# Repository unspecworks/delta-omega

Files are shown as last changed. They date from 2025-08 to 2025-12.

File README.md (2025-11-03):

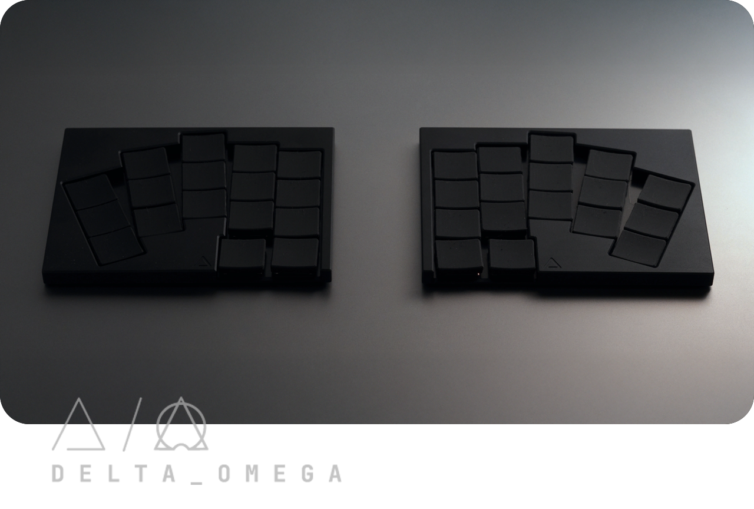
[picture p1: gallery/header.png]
DELTA OMEGA


# DELTA OMEGA

A portable ultra-low-profile (ULP) wireless 3×5+2 split keyboard.

## Overview

- Switch support: Cherry MX ULP or Kailh PG1316s
- 34 keys, splayed and staggered with choc spacing
- Wireless
- CNC aluminum case

## Parameters

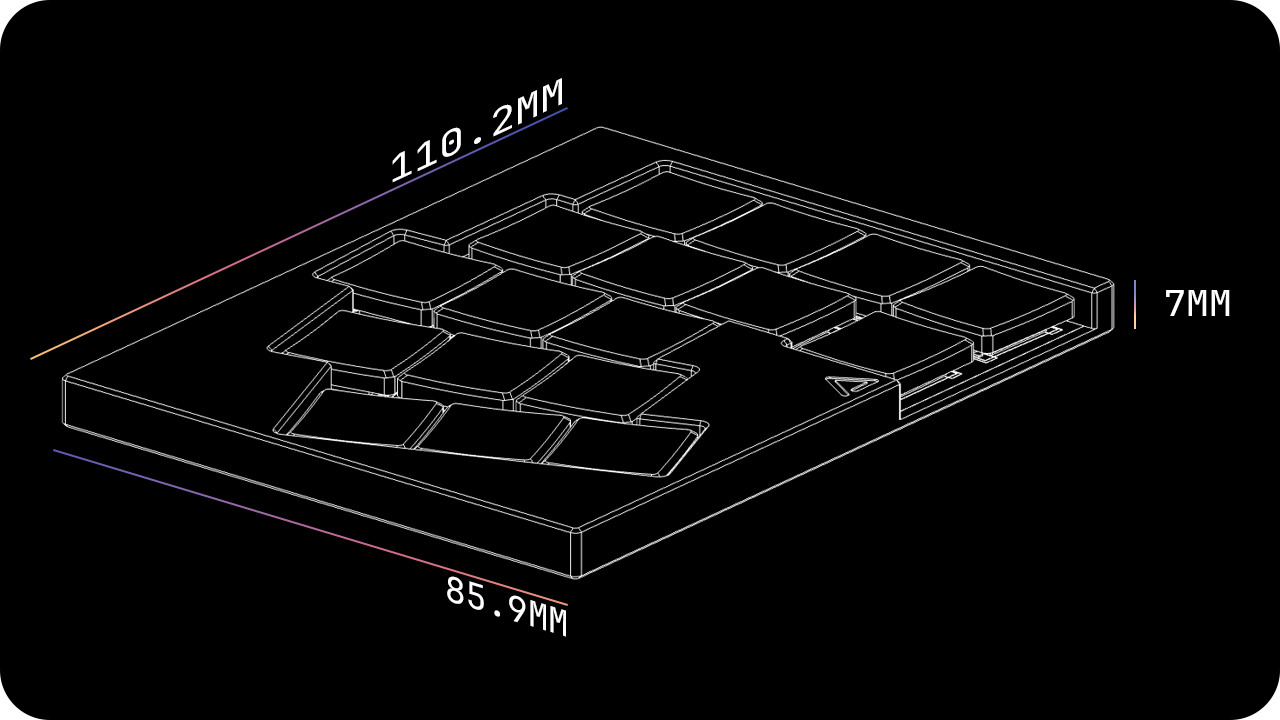
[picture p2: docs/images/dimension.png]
Dimension


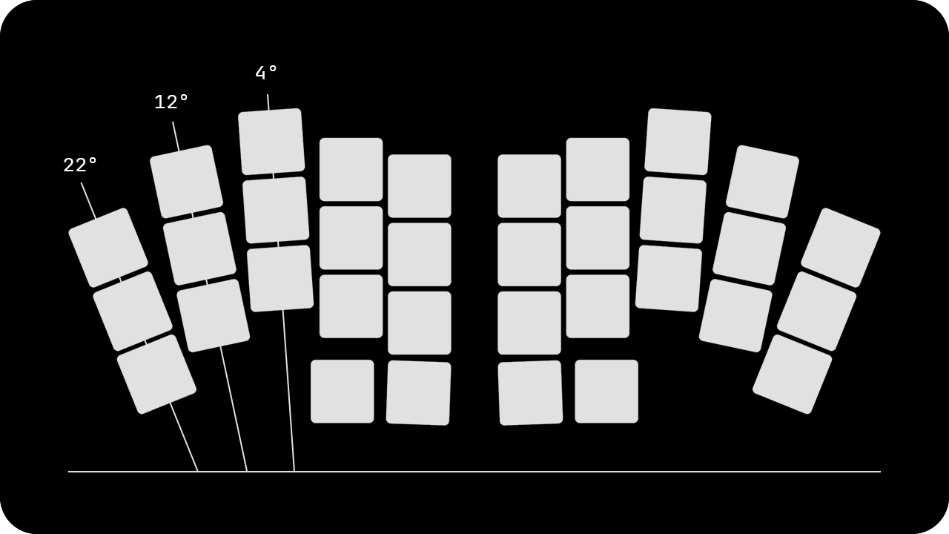
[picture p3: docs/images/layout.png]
Layout


## Documentation

> [!NOTE]
> This is **not** a typical low-profile (LP) or MX build. While it may look familiar, there are enough differences here that skipping the documentation could cause issues. Please take the time to read all notes and guides before starting.

- [Getting Started](./docs/GETTING_STARTED.md)
- [Bill of Materials](./docs/BOM.md)
- [Build Guides](./docs/BUILD_GUIDES.md)
- [Video](https://youtu.be/UktrqN3MlLI)
- [PCB](./pcb/README.md)
- [Case](./case/README.md)
- [ZMK Keyboard Module](https://github.com/unspecworks/zmk-keyboard-delta-omega)
- [Pre-conf ZMK Config](https://github.com/unspecworks/zmk-delta-omega)
- Keycaps
  - [Delta ULP Keycap](https://github.com/unspecworks/delta-ulp-keycap)

## Photos

- [Gallery](./gallery/README.md)
- [Prototype Gallery](./images/README.md)
  - Diff: Port position, Thumb-cluster layout and only hot-plate way.

## Acknowledgments and Inspirations

- [GEIGEIGEIST/TOTEM](https://github.com/GEIGEIGEIST/TOTEM)
- [mikeholscher/zmk-config-mikecinq](https://github.com/mikeholscher/zmk-config-mikecinq)
- [pashutk/Cherry_MX_ULP](https://github.com/pashutk/Cherry_MX_ULP)
- [zmk-rgbled-widget](https://github.com/caksoylar/zmk-rgbled-widget)
- [infused-kim/kb_ergogen_fp](https://github.com/infused-kim/kb_ergogen_fp)
- [ceoloide/ergogen-footprints](https://github.com/ceoloide/ergogen-footprints)
- [kiswitch/kiswitch](https://github.com/kiswitch/kiswitch)

## Limitations and Disclaimer

This is a hobby-driven project. Some aspects may be incomplete, imperfect, or problematic. Use this project **at your own risk**, and note that no warranties or guarantees are provided.

## License

DELTA OMEGA is licensed under [CERN-OHL-W-2.0](./LICENSE.md).

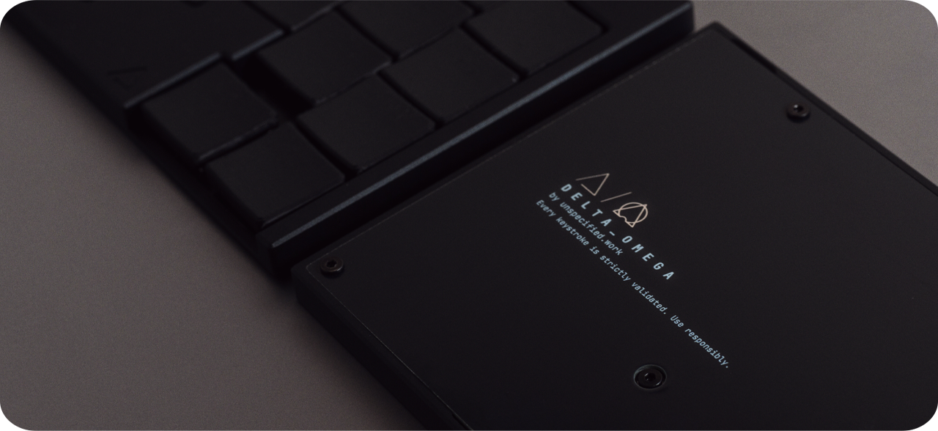
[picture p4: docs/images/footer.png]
footer


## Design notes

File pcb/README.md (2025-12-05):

# PCB

> [!TIP]
> If this is your first visit, please read the [Getting Started guide](./../docs/GETTING_STARTED.md) first.

---

## PCB List

| File | Description | Note |
|---|---|---|
| `delta-omega-rev4-handsolder-both` | Main Left & Right PCB with mouse-bite connection | MB Not tested. |
| `delta-omega-rev4-handsolder-left` | Main Left PCB | |
| `delta-omega-rev4-handsolder-right` | Main Right PCB | |
| `delta_omega_bottom_cover` | Bottom cover PCB plate | Reversible |
| ... |  |  |
| `delta-omega-rev4-smd-both` | SMD Version | :warning: NOT TESTED |

---

## How to Order

This guide is written based on **[JLCPCB](https://jlcpcb.com)**. While other PCB manufacturers may differ slightly, most ordering steps are very similar.

To place an order, you will need the **Gerber archive**. Simply upload the ZIP file found in [./gerbers/](./gerbers/) to the JLCPCB order page.

> [!NOTE]
> In JLCPCB’s Gerber Viewer, the edge cuts for hand-soldering switch may not appear. This is a known JLCPCB viewer issue and does **not** affect the actual manufacturing.

---

### Recommended Options

| Specification | Recommended | Notes |
|---|---|---|
| Base Material | FR-4 | Standard PCB substrate material |
| Layers | 2 | Two-layer board |
| PCB Quantity | As many as needed | |
| Product Type | Industrial / Consumer Electronics | |
| Different Designs | 1 | If uploading a combined left & right PCB Gerber, select **2**.[^1] |
| PCB Thickness | 0.8 mm or 1.6 mm | See [Getting Started](./../docs/GETTING_STARTED.md) for details |
| PCB Color | Your preference | |
| Surface Finish | Your preference | |
| Mark on PCB | Remove Mark | Recommended for a cleaner finish |

[^1]: If not selected, JLCPCB will automatically review your order and guide you to the correct option.

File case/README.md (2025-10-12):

# Case

### Default Case STEP Files
- `delta_omega_rev2_left.step`
- `delta_omega_rev2_right.step`

### Thread Annotation Drawings
These images **must be uploaded when placing an order** to ensure correct threading specifications:
- `delta_omega_rev2_left_thread.png`
- `delta_omega_rev2_right_thread.png`

---

## How to Order

This instructions are **based on JLC CNC**. While other CNC manufacturing services may follow slightly different requirements, in practice most specifications are very similar.

- **Material**: Aluminum 6061 (or something)
- **Surface Finish**: Bead blasting + anodizing recommended
- **Tightest Tolerance**: ISO 2768 (medium) is sufficient
- **Surface Roughness**: Ra3.2 is sufficient
- **Threads**: Yes. be sure to upload the thread annotation images (`left` / `right`) with your order

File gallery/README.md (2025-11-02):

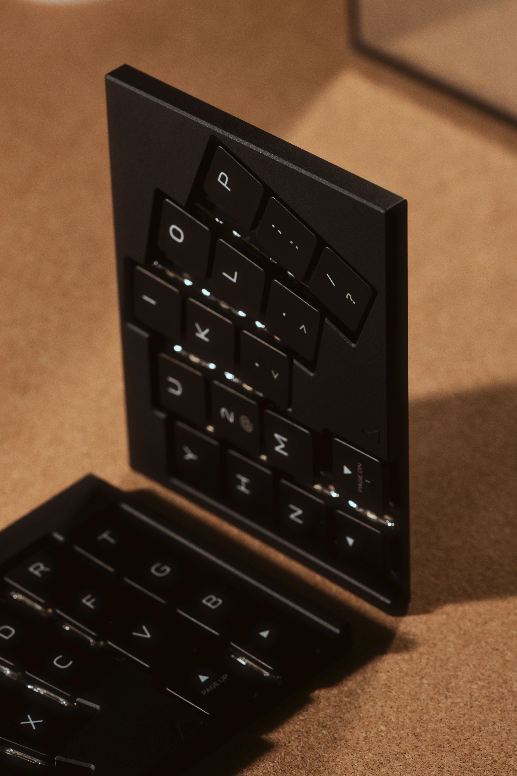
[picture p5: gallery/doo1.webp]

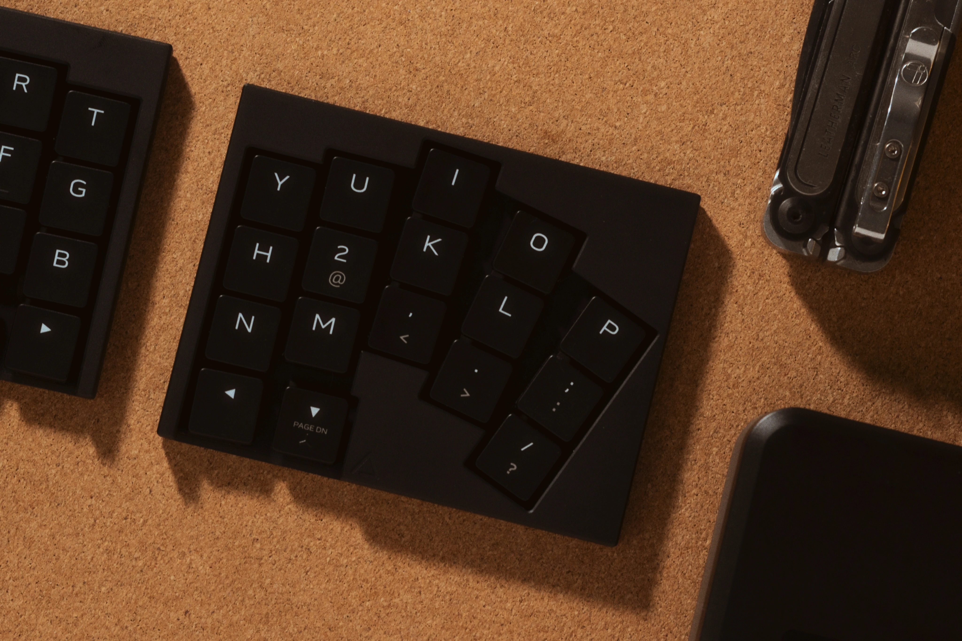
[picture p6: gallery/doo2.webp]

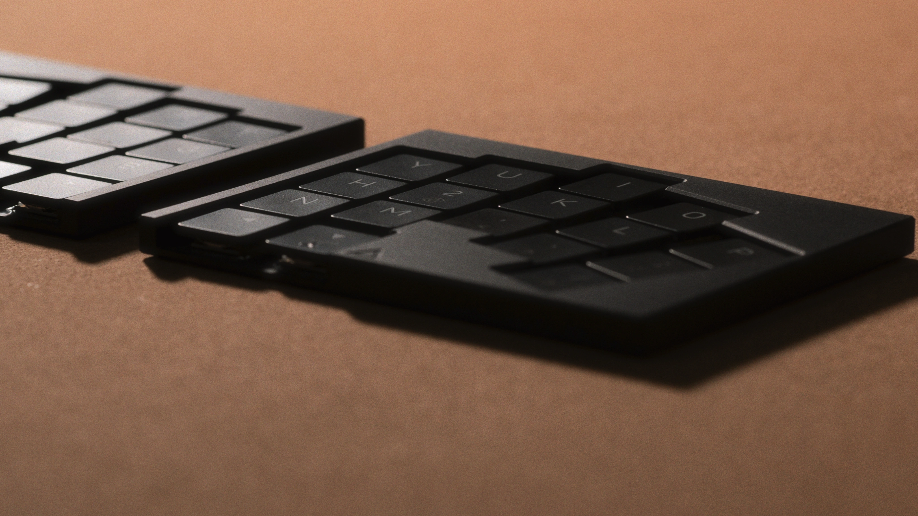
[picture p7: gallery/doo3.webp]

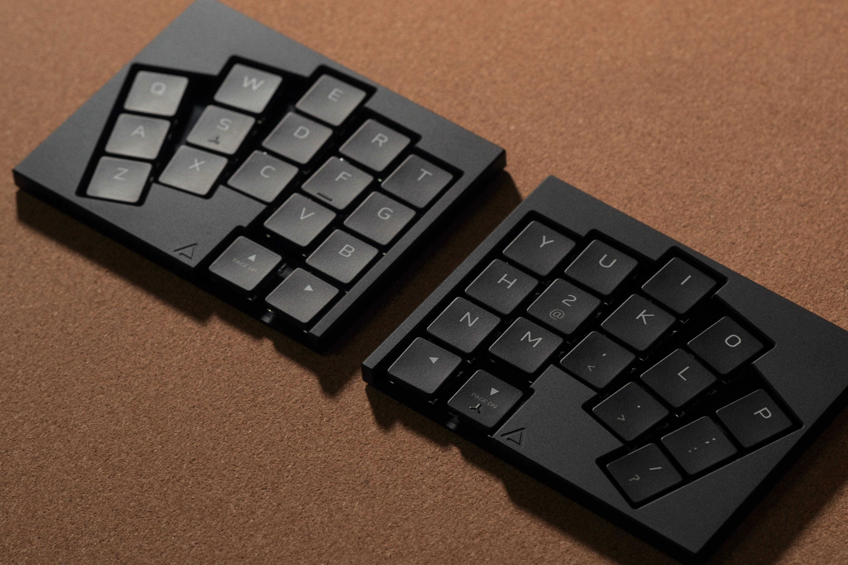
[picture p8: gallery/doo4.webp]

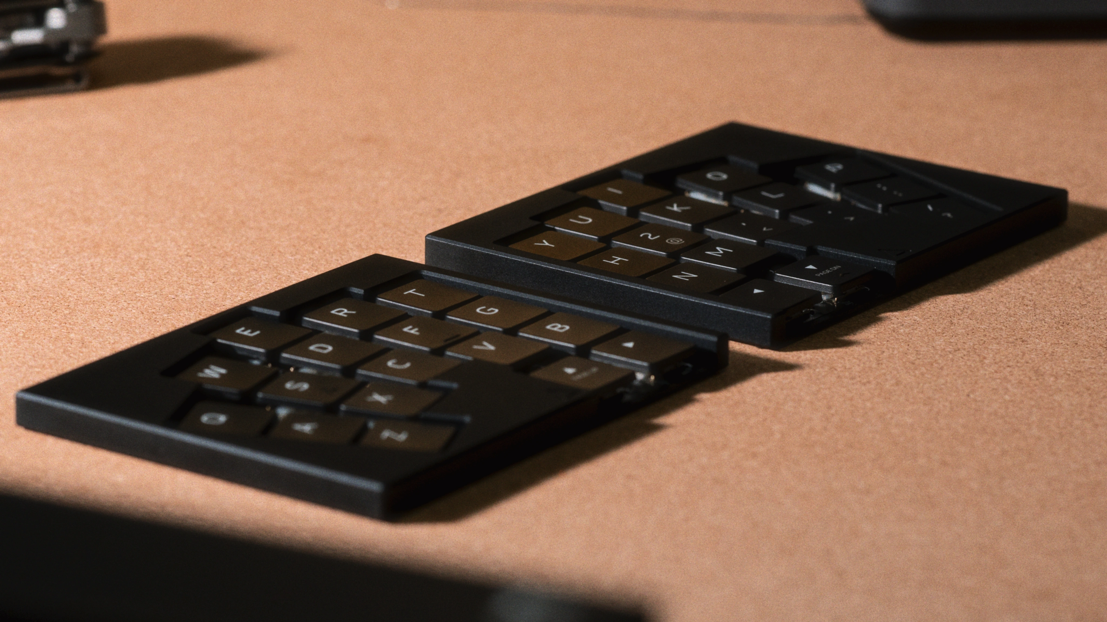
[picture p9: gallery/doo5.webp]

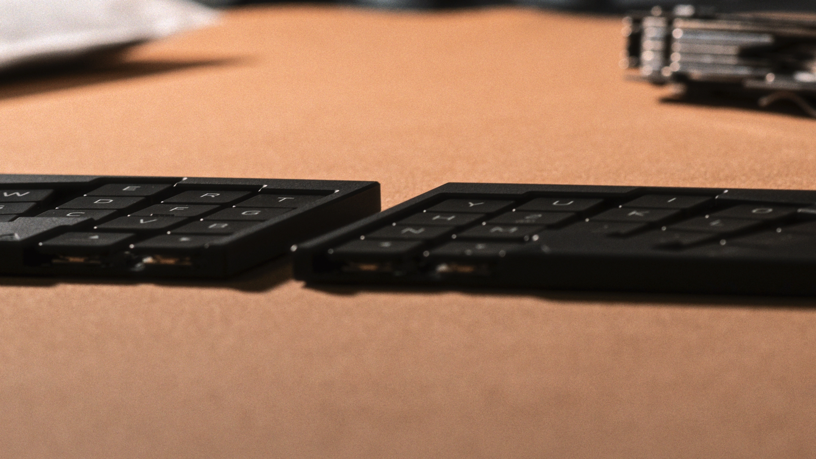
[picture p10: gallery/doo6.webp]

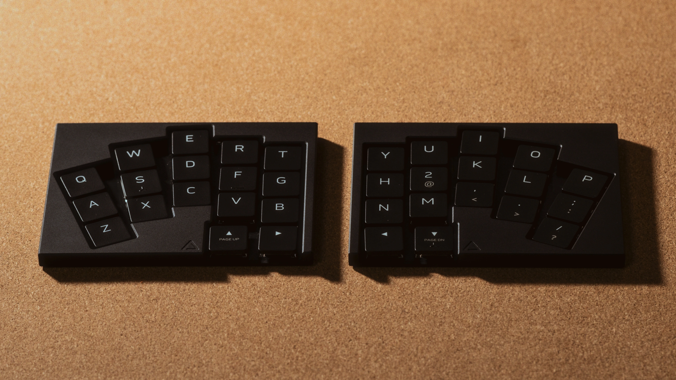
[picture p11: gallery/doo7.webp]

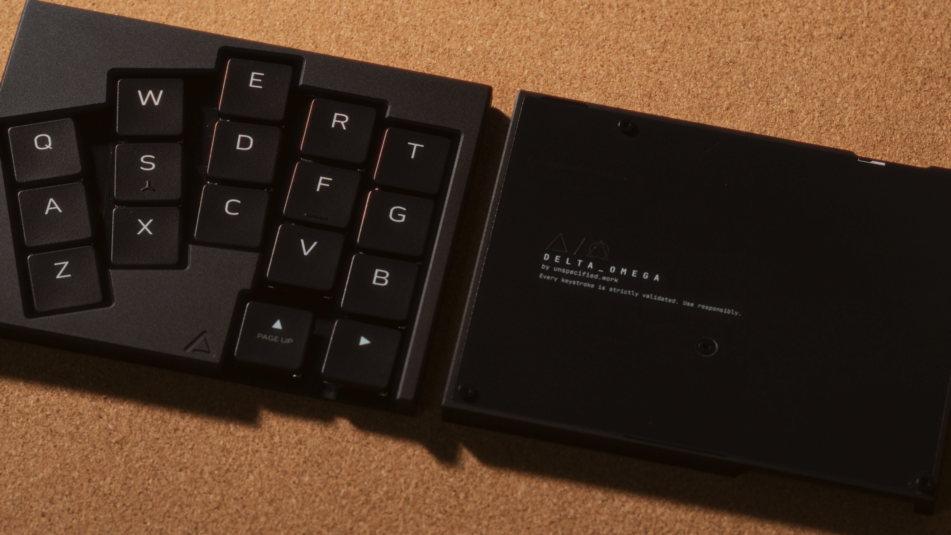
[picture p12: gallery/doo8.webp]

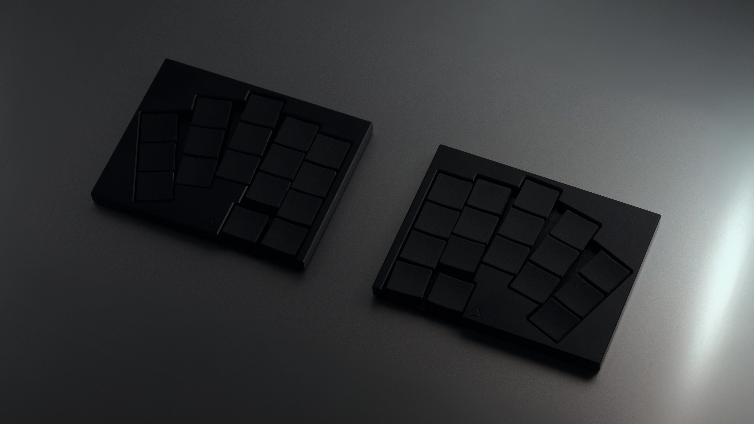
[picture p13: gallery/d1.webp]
d1

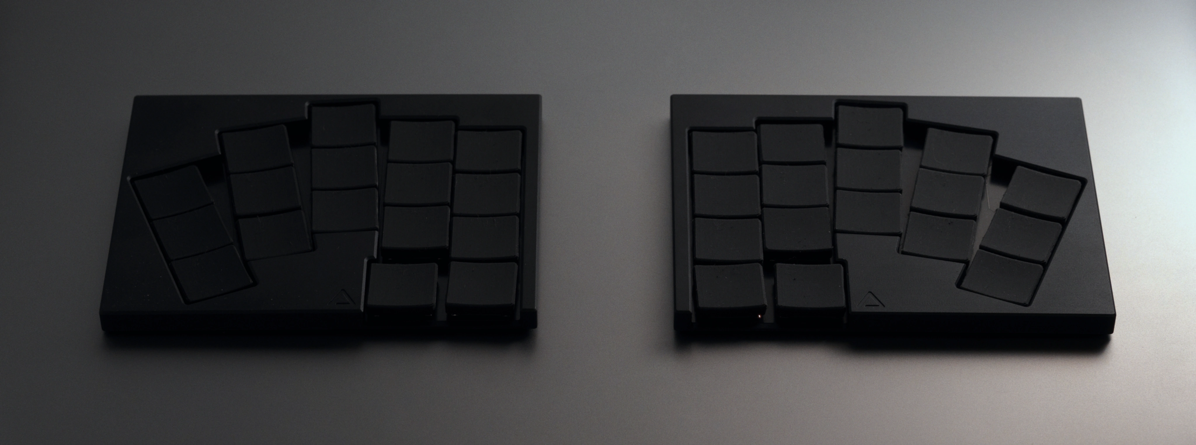
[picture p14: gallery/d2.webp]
d2

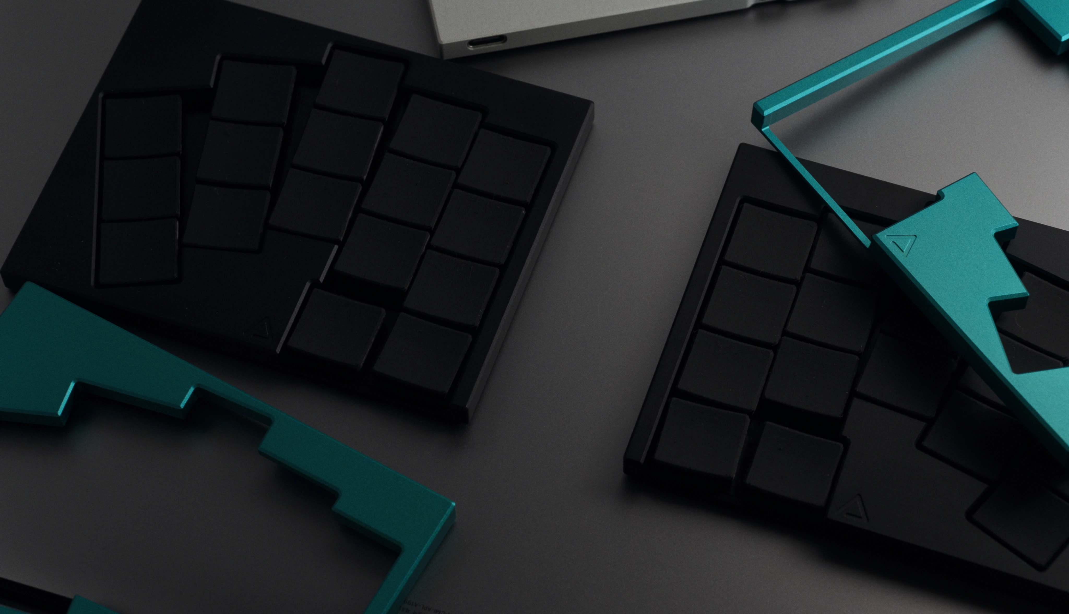
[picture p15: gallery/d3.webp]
d3

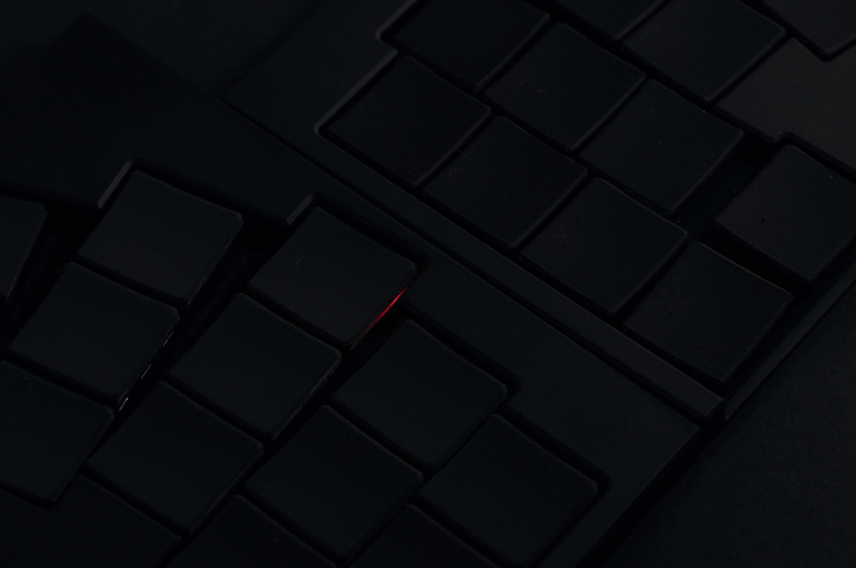
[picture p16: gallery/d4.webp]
d4

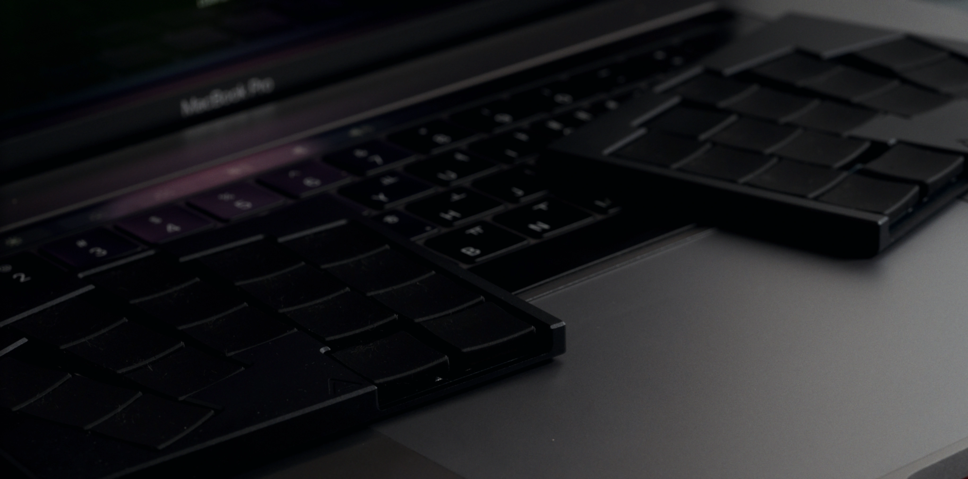
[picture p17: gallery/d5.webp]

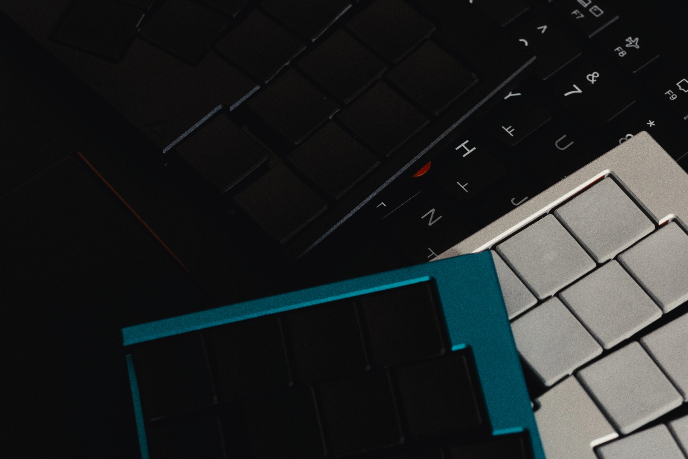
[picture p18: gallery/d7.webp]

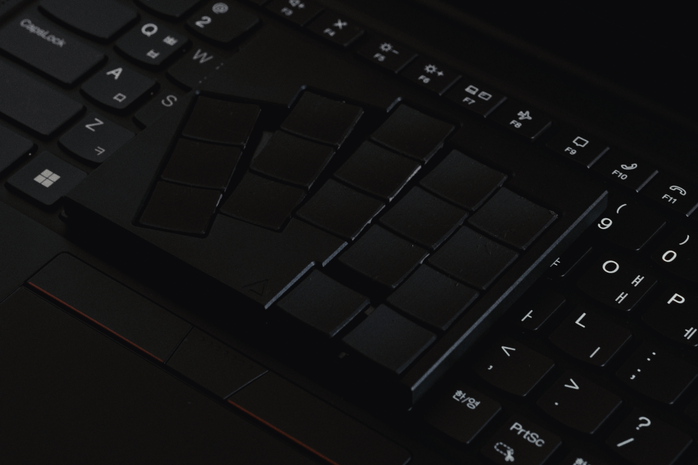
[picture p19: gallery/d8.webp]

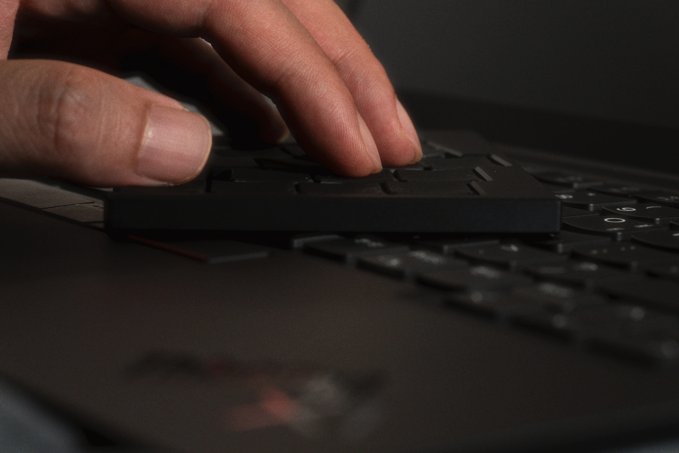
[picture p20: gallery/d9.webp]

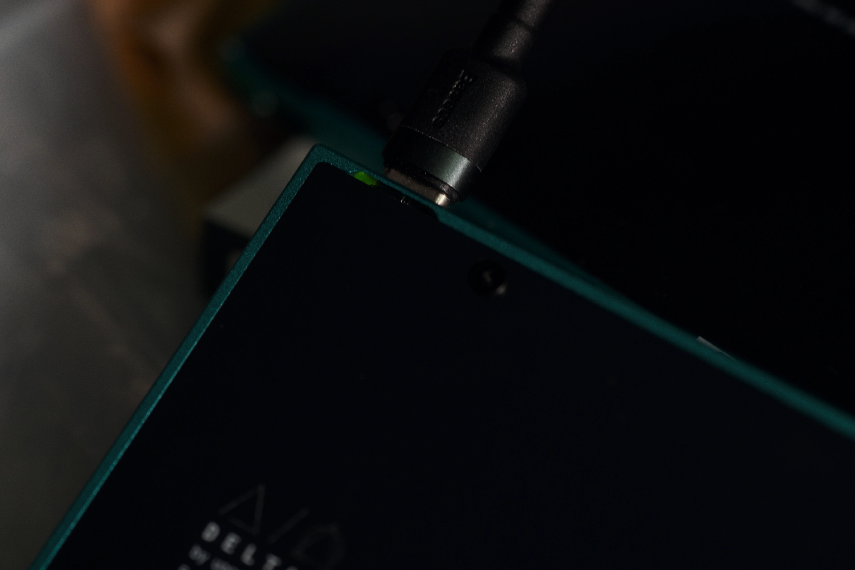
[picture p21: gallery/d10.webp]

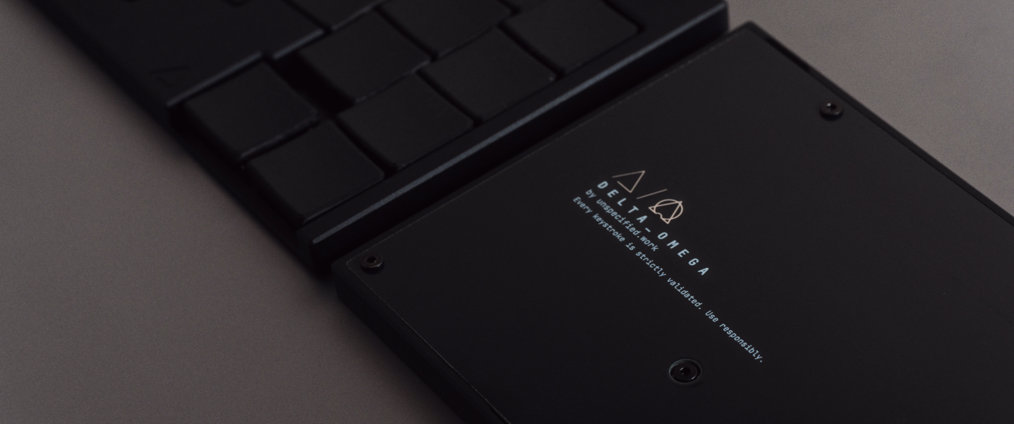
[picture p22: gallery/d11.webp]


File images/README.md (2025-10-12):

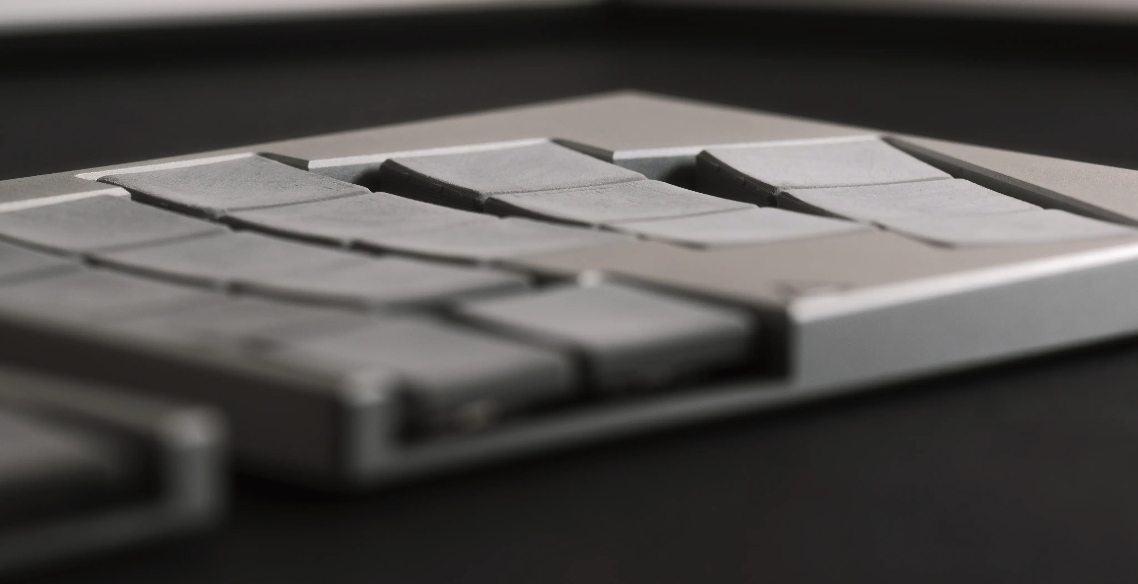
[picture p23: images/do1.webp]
d1

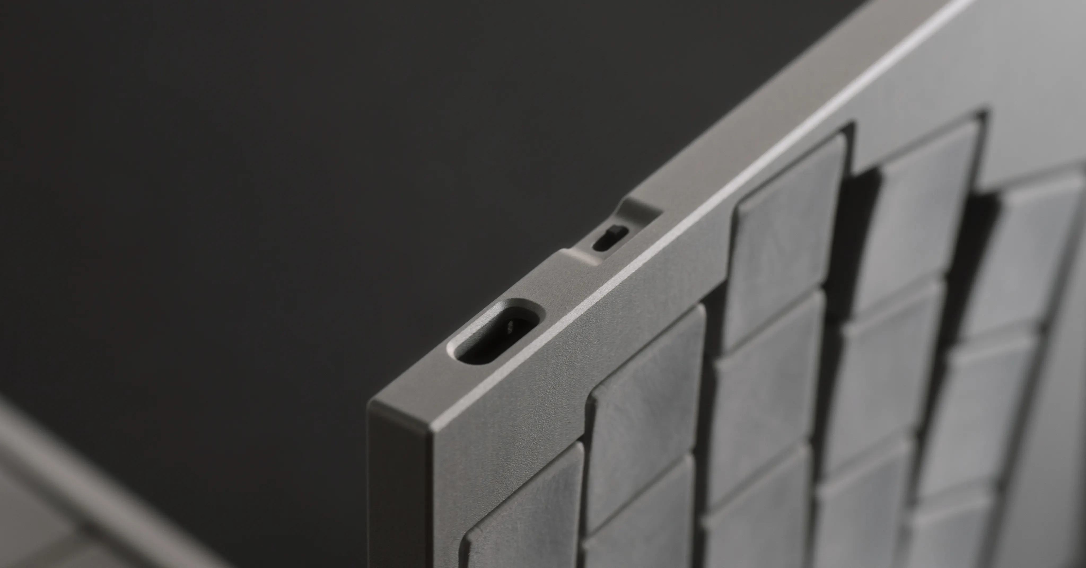
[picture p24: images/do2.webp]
d2

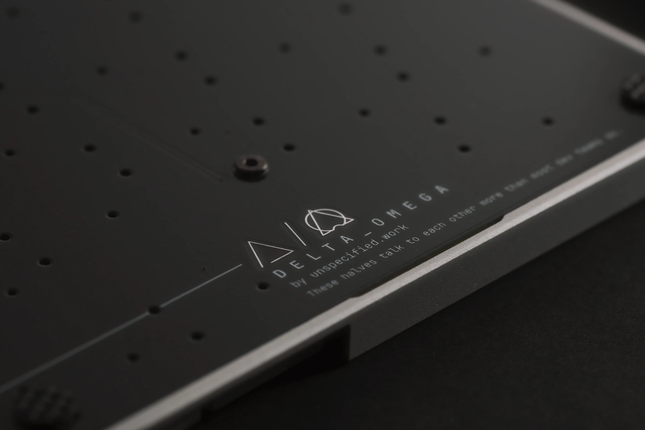
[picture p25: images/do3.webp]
d3

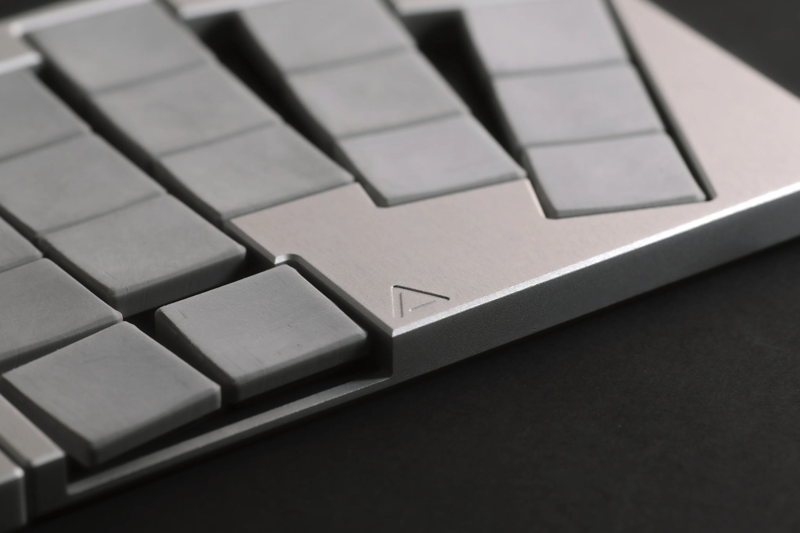
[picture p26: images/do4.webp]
d4

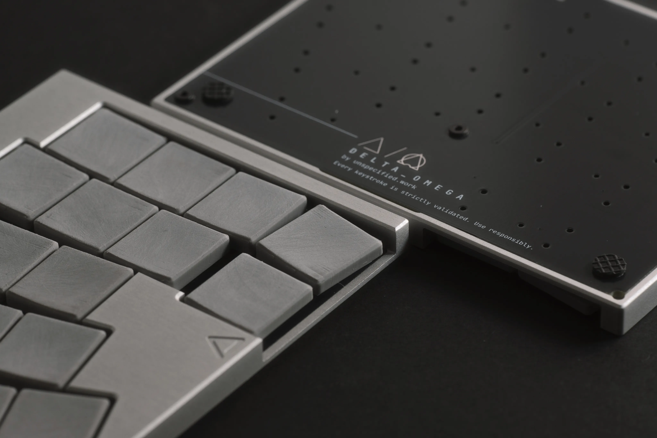
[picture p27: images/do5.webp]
d5

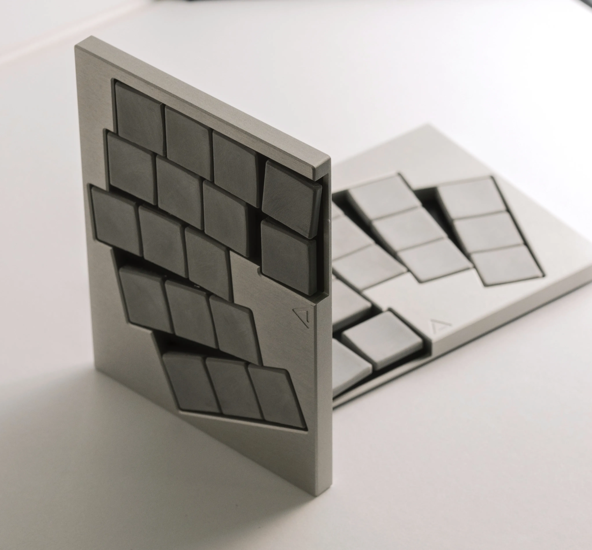
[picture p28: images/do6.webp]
d6

d7
d8
d9
d10

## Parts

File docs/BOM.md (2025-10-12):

# Bill of Materials

| Component | Specification | Quantity | Notes  |
|---|---|---|---|
| MCU Controller | SeeedStudio XIAO nRF52840 | 2 | |
| ULP Switches | Cherry MX ULP or Kailh PG1316s | 34 | |
| ULP Keycap | | 34 | |
| Power Switches | MK-12C02 | 2 | |
| Reset Switches | EVQ-PUL02K | 2 | Compatible with EVQ-PU[A\|C\|J\|L]02K |
| Diodes | SOD-123 | 34 | 1N4148W |
| Batteries | 3.7 V LiPo | 2 | Maximum size: 25.2 mm × 17.7 mm × 4.2 mm |
| Screws | M2 × 3 mm | 10 | If countersink is not used, choose ultra-low head screws (ex. 0.8 mm) |
| LEDs | 0805 (2012 Metric) | 6 | Optional |
| LED Resistors | 1206 (3216 Metric) 220Ω ~ 470Ω | 6 | Optional |
| Magnets | Rounded, OD 8 mm, 3 mm thickness, minimum N52 grade | 6 | Optional |
| ESD Protection Capacitor | 1206 (3216 Metric) 1nF 50V [C0G\|NP0\|X7R] | 2 | Optional |
| ESD Protection Resistor | 1206 (3216 Metric) 1MΩ | 2 | Optional |

## Next Steps

- [Build Guides](./BUILD_GUIDES.md)

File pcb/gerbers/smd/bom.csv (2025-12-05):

Designator | Footprint | Quantity | Value | LCSC Part #
_4, _3, _2, | Mousebite_5 | 4
C1, C2 | 1206 | 2 | C_1206_1NF | C1845
D1, D10, D11, D12, D13, D14, D15, D16, D17, D18, D19, D2, D20, D21, D22, D23, D24, D25, D26, D27, D28, D29, D3, D30, D31, D32, D33, D34, D4, D5, D6, D7, D8, D9 | SOD123 | 34 | SOD123 | C917030
H1, H2 | mounting_hole_plated | 2
L1, L4 | 0805 | 2 | LED_0805_R | C19171391
L2, L5 | 0805 | 2 | LED_0805_G | C25170728
L3, L6 | 0805 | 2 | LED_0805_B | C19273154
MCU1, MCU2 | smdXIAO-nRF52840 | 2 | XIAO-nRF52840-SMD
MH1, MH2, MH3, MH4, MH5, MH6, MH7, MH8 | mounting_hole_npth | 8
POWER1 | power_switch | 1 | PWR_SW | C2911519
PWR_SW | power_switch | 1 | POWER1 | C2911519
R1, R2, R3, R4, R5, R6 | 1206 | 6 | R_1206 _220R | C17957
R7, R8 | 1206 | 2 | R_1206_1MR | C17927
RST1, RST2 | reset_switch_smd_side | 2 | SW_RST | C79175
SW1, SW10, SW11, SW12, SW13, SW14, SW15, SW16, SW17, SW18, SW19, SW2, SW20, SW21, SW22, SW23, SW24, SW25, SW26, SW27, SW28, SW29, SW3, SW30, SW31, SW32, SW33, SW34, SW4, SW5, SW6, SW7, SW8, SW9 | GENERIC_ULP_SMD | 34 | ULP_SW | C48887637
TH1, TH2 | simple_tht_fp | 2

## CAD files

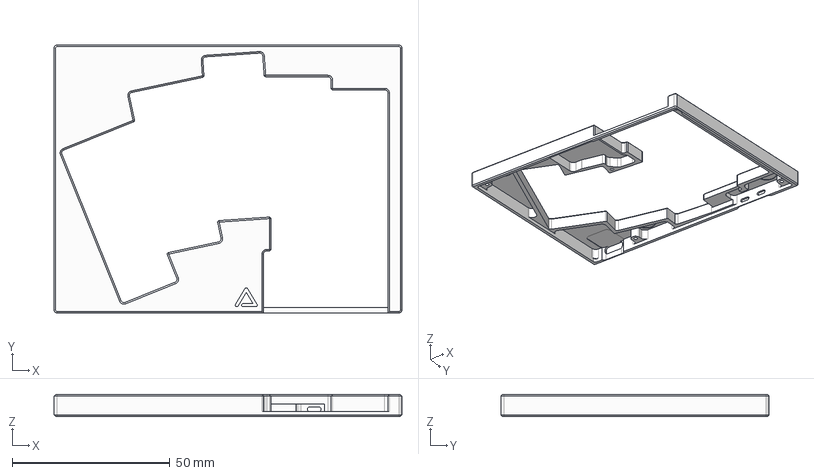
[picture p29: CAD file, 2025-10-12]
case/delta_omega_rev2_left.step
110.2 x 84.9 x 7.00 mm

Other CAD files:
case/delta_omega_rev2_right.step

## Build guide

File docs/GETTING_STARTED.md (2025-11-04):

# Getting Started

Please read this document carefully before beginning your build.
It may be long and tedious, but every section is written with only the most essential information in mind.

## Step 1: Choosing Your Switches

This keyboard supports **Cherry MX ULP** or **Kailh PG1316S** switches.

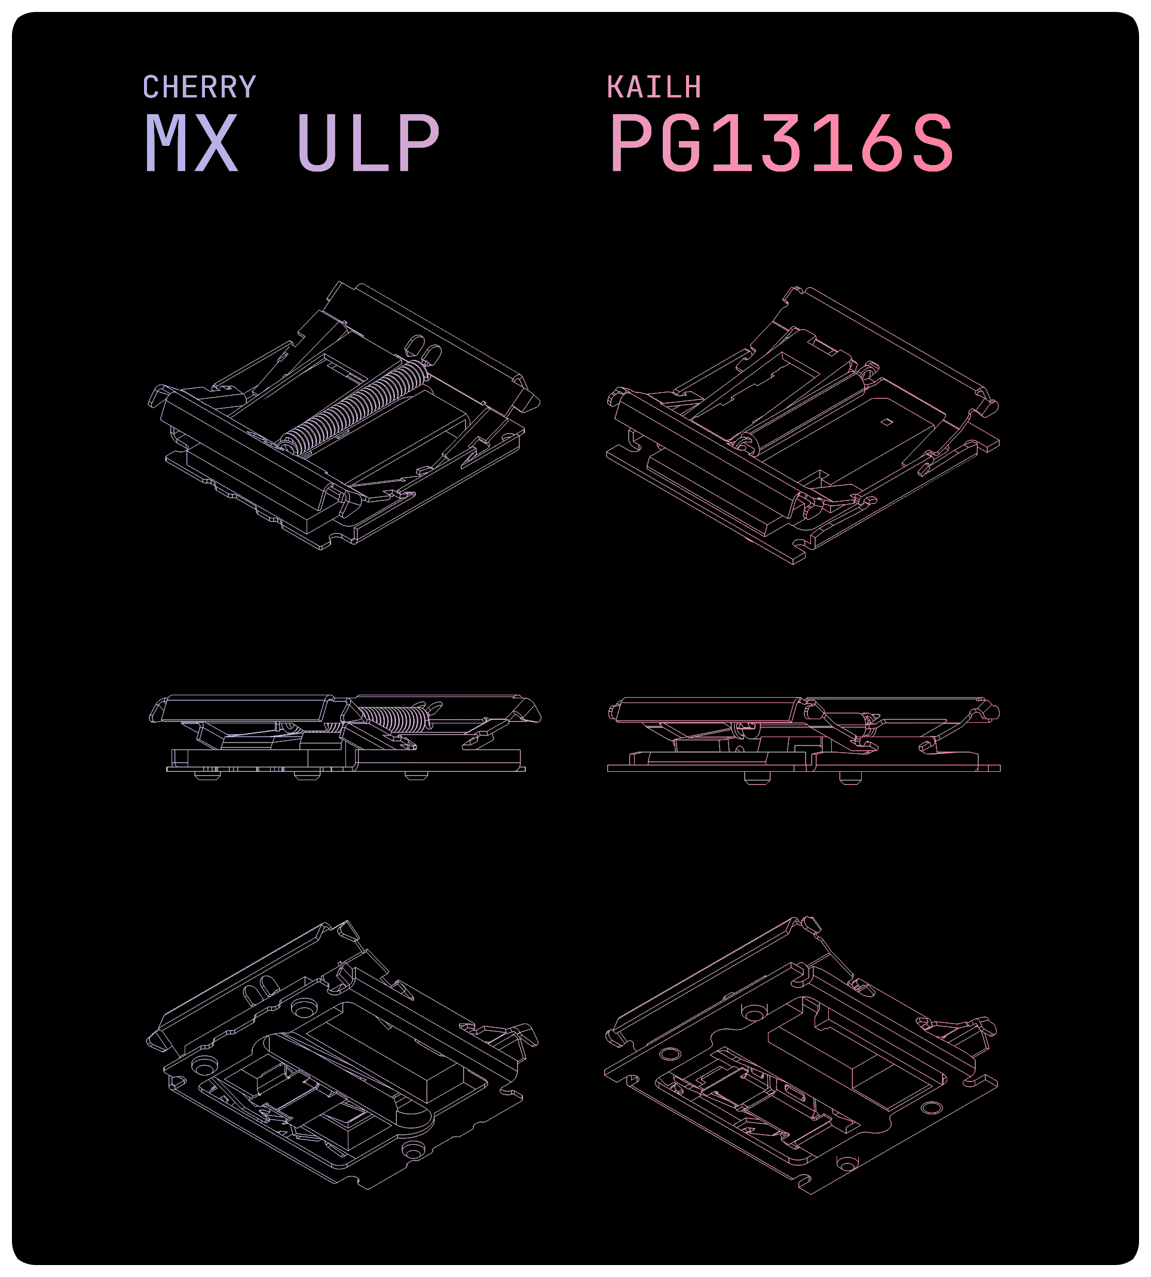
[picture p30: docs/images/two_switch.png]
Switches


### Cherry MX ULP
Developed by Cherry, available in both clicky and tactile versions.
- Actuation force: 65 gf (relatively heavy)
- Availability: very limited. both switches and compatible keycaps are difficult to source

#### Where to Buy
- Large distributors such as Mouser (very expensive)
- Geonworks (appears to be restricted to the Korean domestic market)

- Or, harvesting parts by desoldering from some commercial products. More details [here](https://github.com/pashutk/Cherry_MX_ULP).

### Kailh PG1316s
Developed by Kailh, with specifications and mechanism very similar to Cherry MX ULP.
- Actuation force: 35 gf, 65 gf
- Easier to source than Cherry MX ULP
- Often sold together with compatible keycaps

#### Where to Buy *(unverified)*
- Modulo Industries (US)
- Holykeebs (US)
- Keycapsss (EU)

### Which Should You Choose?
It largely depends on availability. Due to market scarcity, the **best switch is usually the one you can actually get** at the time of building. and don't forget the acuation force.

## Keycaps

The DELTA OMEGA uses **Choc spacing (18 × 17 mm)**.
- Standard ULP keycaps are **16 × 16 mm**. Using them will leave visible gaps between keys. Functionally this is fine, but low height and little wider gaps with higher quality. Refer to [Dell's Stock Cherry ULP Keycap Image](./../gallery/doo4.webp) and [Custom printed Keycap Image](./../gallery/d2.webp).

#### Suggested Approach
- Consider custom-printed ULP keycaps. Be aware: due to thin walls, 3D printed ULP keycaps can be fragile and prone to printing issues.
- You can loot keycaps from repair modules or broken parts of Dell laptop keyboards that use some Cherry MX ULP switches. Check [here](https://github.com/pashutk/Cherry_MX_ULP?tab=readme-ov-file#where-to-source) for reference.

- Removing ULP keycaps is difficult; my chosen method is to use FDM-printed keycaps and destroy them (cut with a soldering iron or nippers) when replacements are needed.

> [!TIP]
> [@mikeholscher’s notes on removing keycaps](https://github.com/mikeholscher/zmk-config-mikecinq?tab=readme-ov-file#about-removing-keycaps) may be helpful.

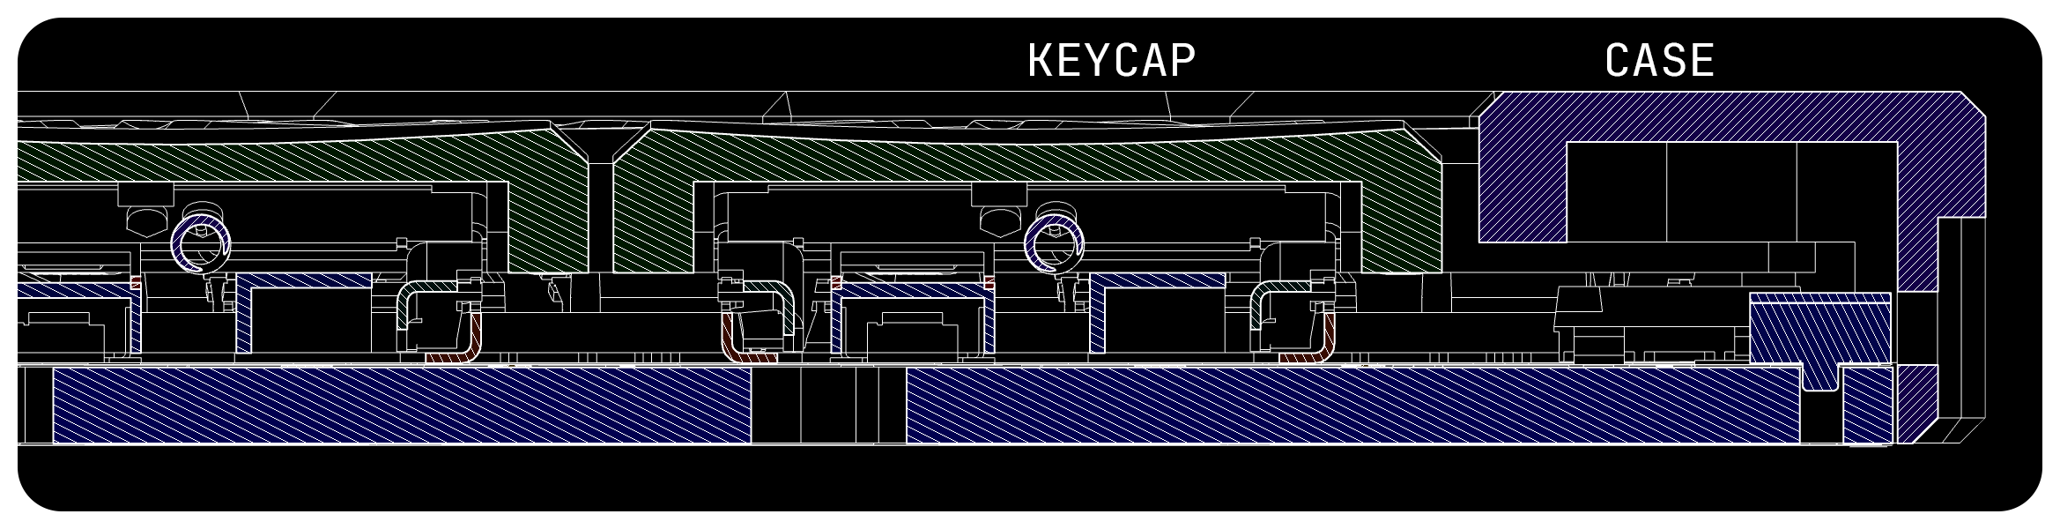
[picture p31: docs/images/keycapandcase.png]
Keycap and case height


#### Height Considerations
The DELTA OMEGA prioritizes portability, so the case is slightly taller than the switches.
- Ideally, the keycap should sit just below the case edge (≈0.3 mm).
- Some users may find this uncomfortable. consider high-profile keycaps as an alternative.

## Soldering

Both switch types are SMT by default, designed for hot plate or reflow soldering.
To make the board more approachable, footprints were modified for **hand soldering**. This still requires moderate skills.

## PCB

### Main PCB
The PCB is **non-reversible** — you will need a left and right pair.

Two ordering options:
1. A single Gerber including both left and right PCBs
2. Separate left and right PCB files

**Why?**
Ordering both together requires mouse-bites or V-cuts to split, leaving rough edges. Since DELTA OMEGA leaves the bottom PCB exposed, rough edges and tight tolerances can cause issues.

Cost difference is negligible (1~2 USD), so choose based on preference.

### PCB Thickness

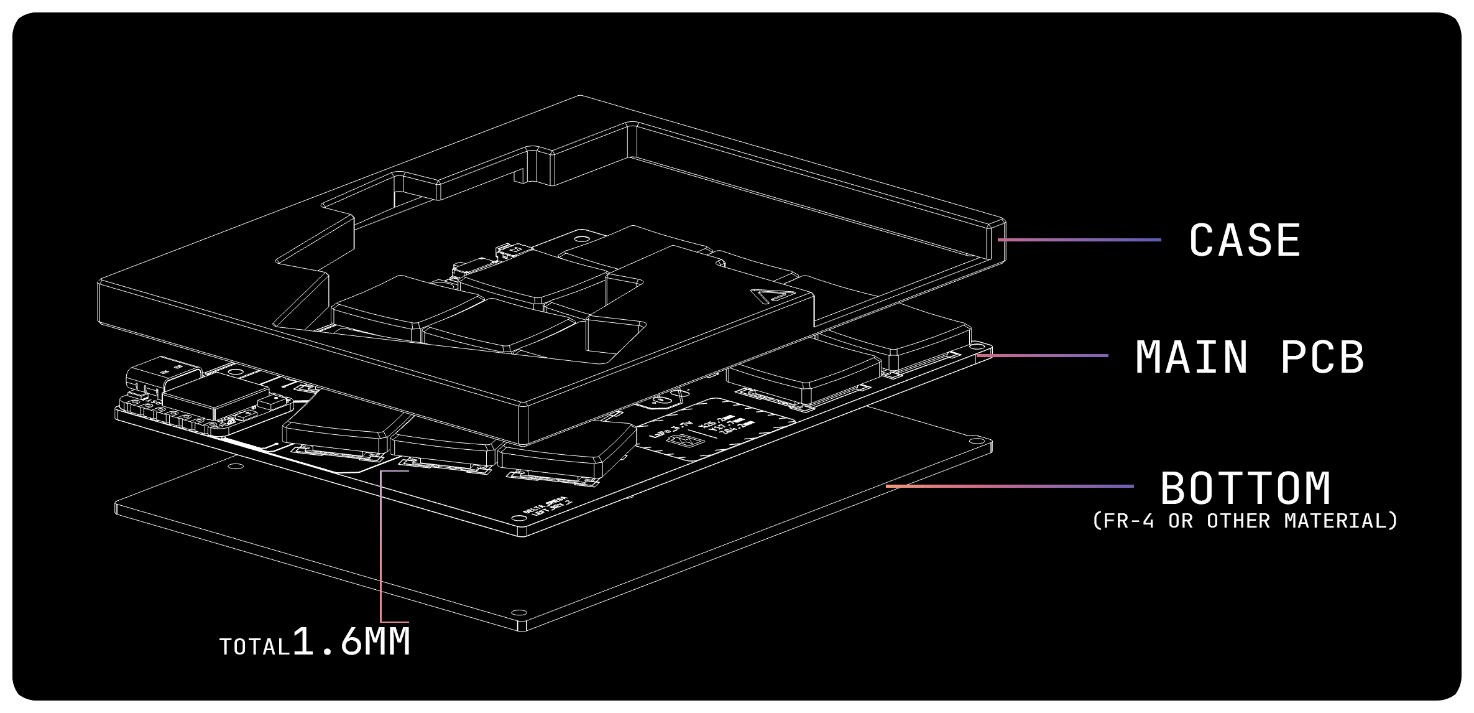
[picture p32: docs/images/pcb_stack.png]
PCB Stack


Options:
- Single 1.6mm PCB
- Combination of 0.8mm main PCB + 0.8mm bottom cover

If not an issue, you can freely choose thickness.

> [!TIP]
> The cover can be countersunk for a flat bottom. Note that 0.8mm is too thin for a perfect countersink, and the lower right corner (on the left half) is especially challenging.

> [!TIP]
> Customize your cover with some designs.

## Case

The case is recommended to be **CNC aluminum**.
Due to the thin and portability focus, a rigid case material ensures durability.

### Cost
CNC machining is often the largest concern.

- With JLC CNC (Aluminum A6061, bead blasting + anodizing):
  Approx. **32 USD per side**
- Prices may vary, and should only be considered a rough reference

> [!TIP]
> Ordering multiple units (e.g., with friends) significantly reduces cost — as low as 30 USD per side. Coupons and alternative CNC shops can further reduce expenses.

Combined PCB + CNC costs are generally around **80–100 USD (excluding shipping/tax)**.

### Magnets
Three magnets can be installed inside the case to allow the halves to snap together for portability.

- This is optional; if you’re concerned about scratches, consider alternative storage solutions.
- Refer to the BOM for recommended magnet specifications (tested values).

### CNC Experience with JLC

For prototyping, I placed around six CNC orders from JLCCNC. Overall, the quality was acceptable: some uneven chamfering and minor surface scratches (barely noticeable) were present. But one piece arrived slightly warped(deformation), which is understandable given the hollow structure and thin sidewalls. so it carries an inherent risk of deformation. In my case, about 0.3 mm of tolerance shift occurred, requiring some manual adjustment with hand tools.

If you encounter similar issues, it would be a good idea to discuss them directly with JLC and work out possible solutions.

## LED Indicator

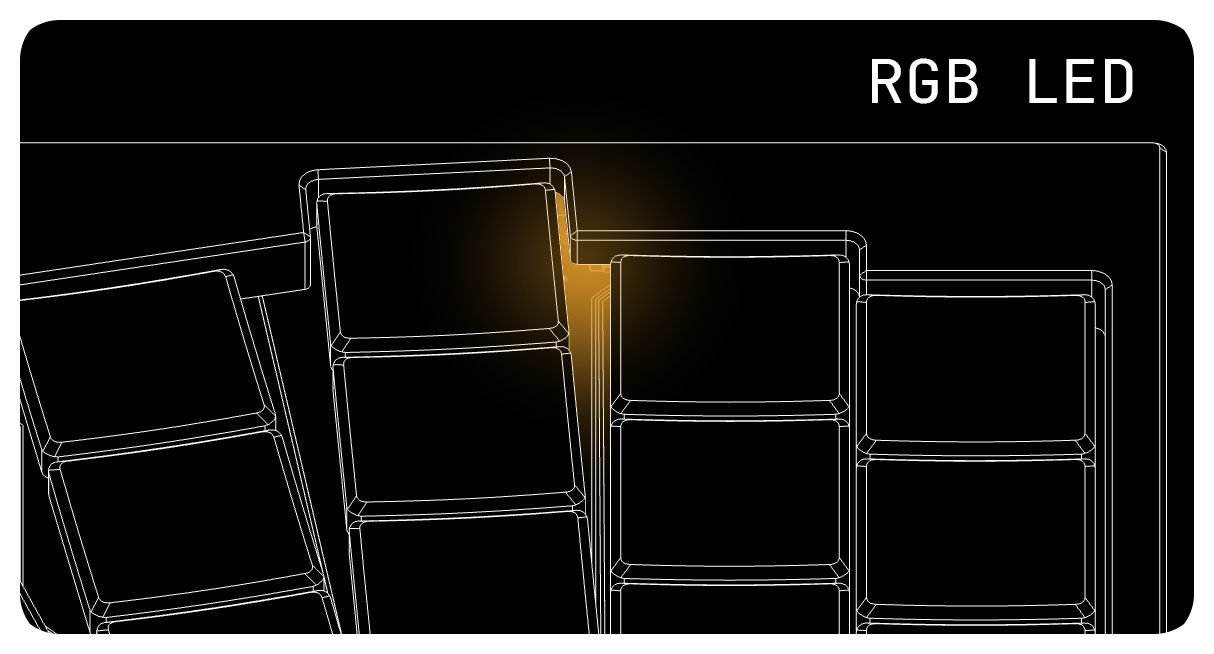
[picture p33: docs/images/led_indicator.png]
LED Indicator


The design utilizes three individual LEDs as an indirect glow indicator. The color may be chosen according to user preference; however, the default configuration is Red, Green, and Blue. Refer to the [zmk-rgbled-widget](https://github.com/caksoylar/zmk-rgbled-widget) documentation to adjust the settings according to your preference.

When operating LEDs at 3.3 V, it is recommended to install appropriate resistors. Using resistors with lower resistance values will increase brightness, but also result in higher battery consumption and, to a lesser extent, greater load on the MCU. Note that even when identical resistor values are used, brightness may vary by LED color. Consider these factors when selecting resistor values. If uncertain, a 220Ω resistor is generally a safe and effective choice.

## Battery

You can use a 3.7V Li-Po battery. The size must fit within **25.2 mm × 17.7 mm × 4.2 mm**.
However, the commonly available **401725** model may not fit properly. This is because typical specifications often exclude the size of the protection circuit, and lithium polymer batteries tend to have significant packaging tolerances.

Be sure to check the actual dimensions before purchasing. Do not force the battery into place.

---

## Next Steps

- [Bill of Materials](./BOM.md)
- [Build Guides](./BUILD_GUIDES.md)

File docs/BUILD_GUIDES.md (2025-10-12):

# Build Guides

This document covers the **hand-solder version** of the build process.

## Required Tools and Materials
- Soldering iron
- Solder wire
- Flux
- Ventilation system
- Knife or precision cutter
- Silicone adhesive or cyanoacrylate (For magnets)
- Multimeter

If working with a mouse-bited PCB, you will also need:
- Plier
- Mask
- Sandpaper

⚠️ **Note**: Be cautious when sanding PCBs. Fine dust can be hazardous.

> [!CAUTION]
> Always prioritize safety. Proper ventilation, a clean workspace, and appropriate protective equipment are **mandatory**, not optional.

## Power Switch

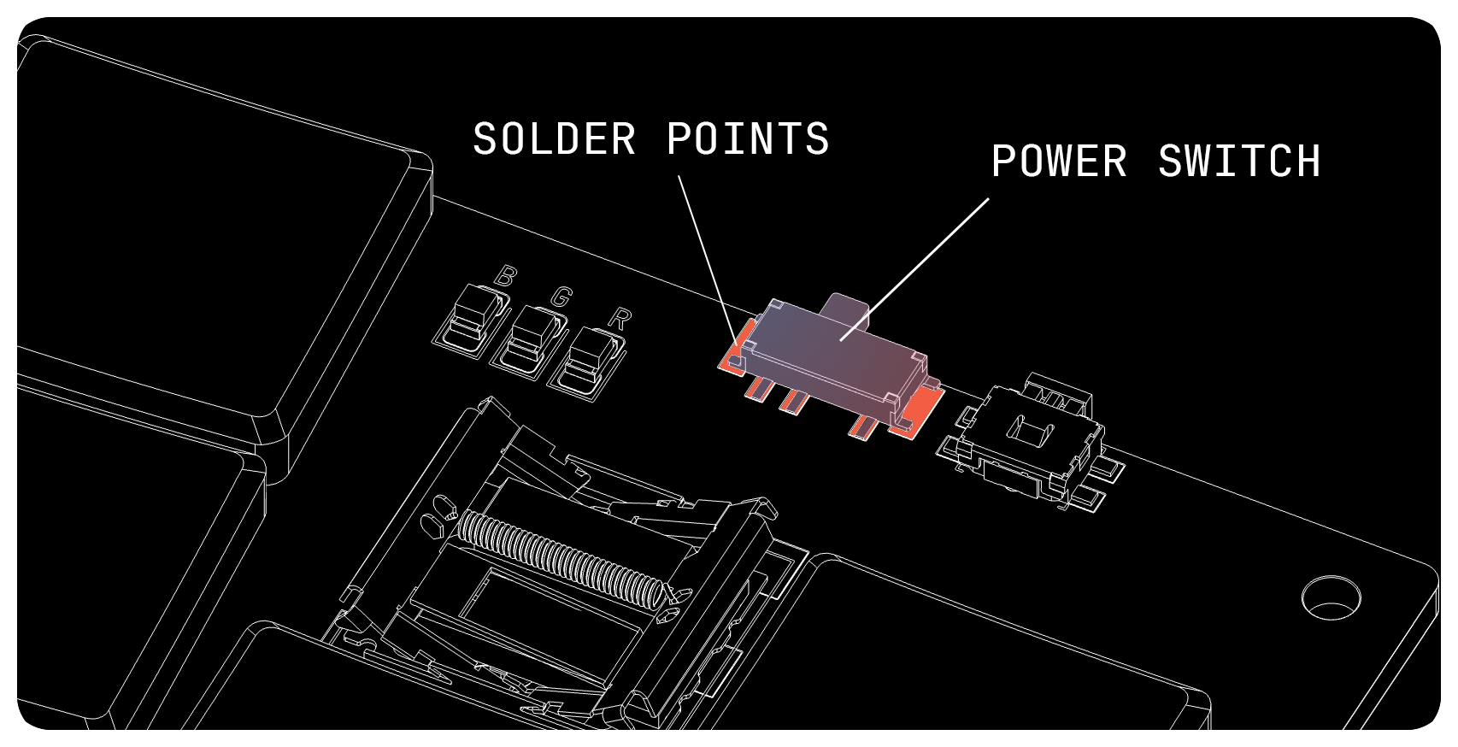
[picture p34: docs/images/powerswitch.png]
Power Switch


1. Apply solder to one of the wide pads.
2. Place the switch in position and hold it while reflowing the solder to tack it in place.
3. Solder the opposite wide pad.
4. Finally, solder the three smaller legs.

Correct alignment is essential (the boss features will help position the part).

> [!CAUTION]
> Keep the switch in the **OFF position (all the way to the right)** during the entire build. This is critical.

## Reset Switch

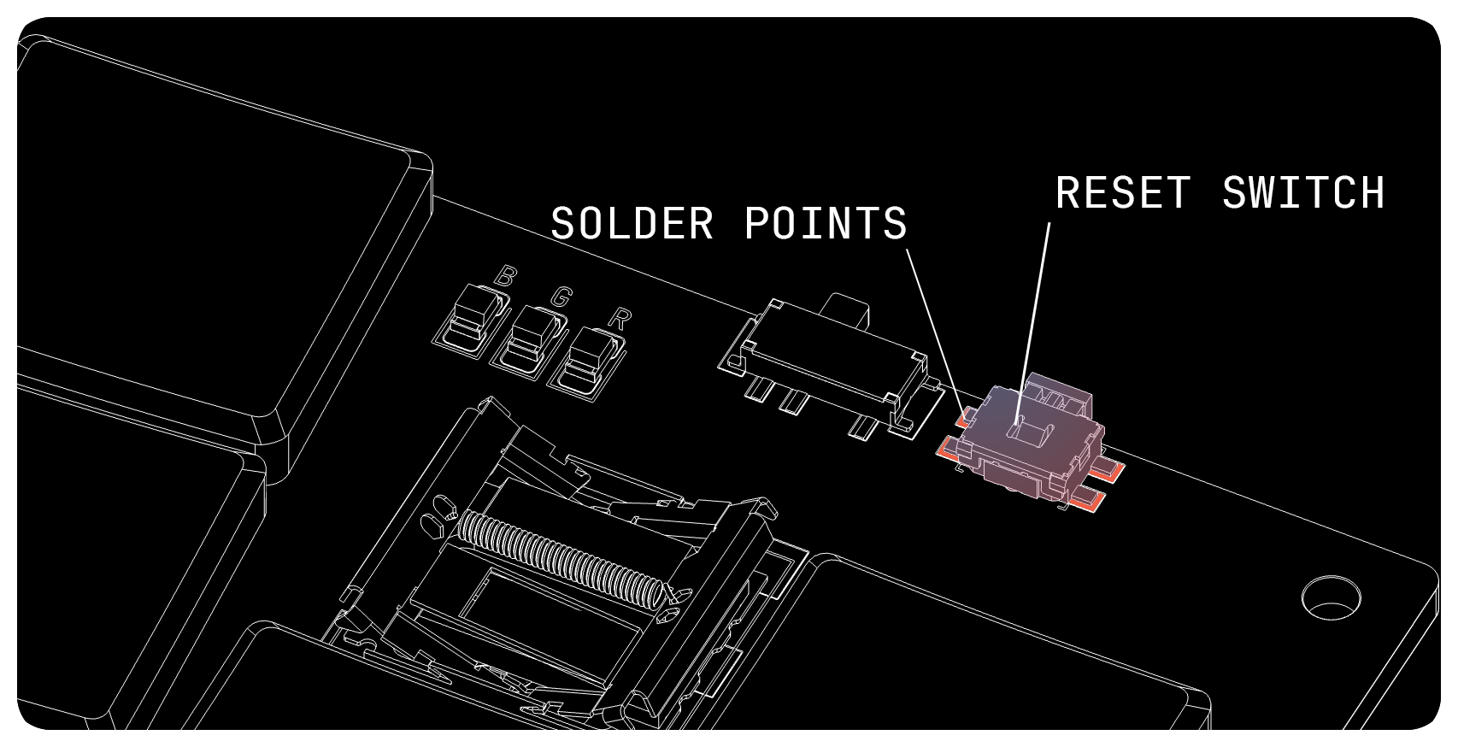
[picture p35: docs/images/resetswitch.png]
Reset Switch


The process is nearly identical to the power switch:

1. Pre-solder one pad.
2. Position the switch and reflow to hold it in place.
3. Solder the remaining three pads.

As with the power switch, correct alignment is important (boss features assist here).

## (Optional) LED

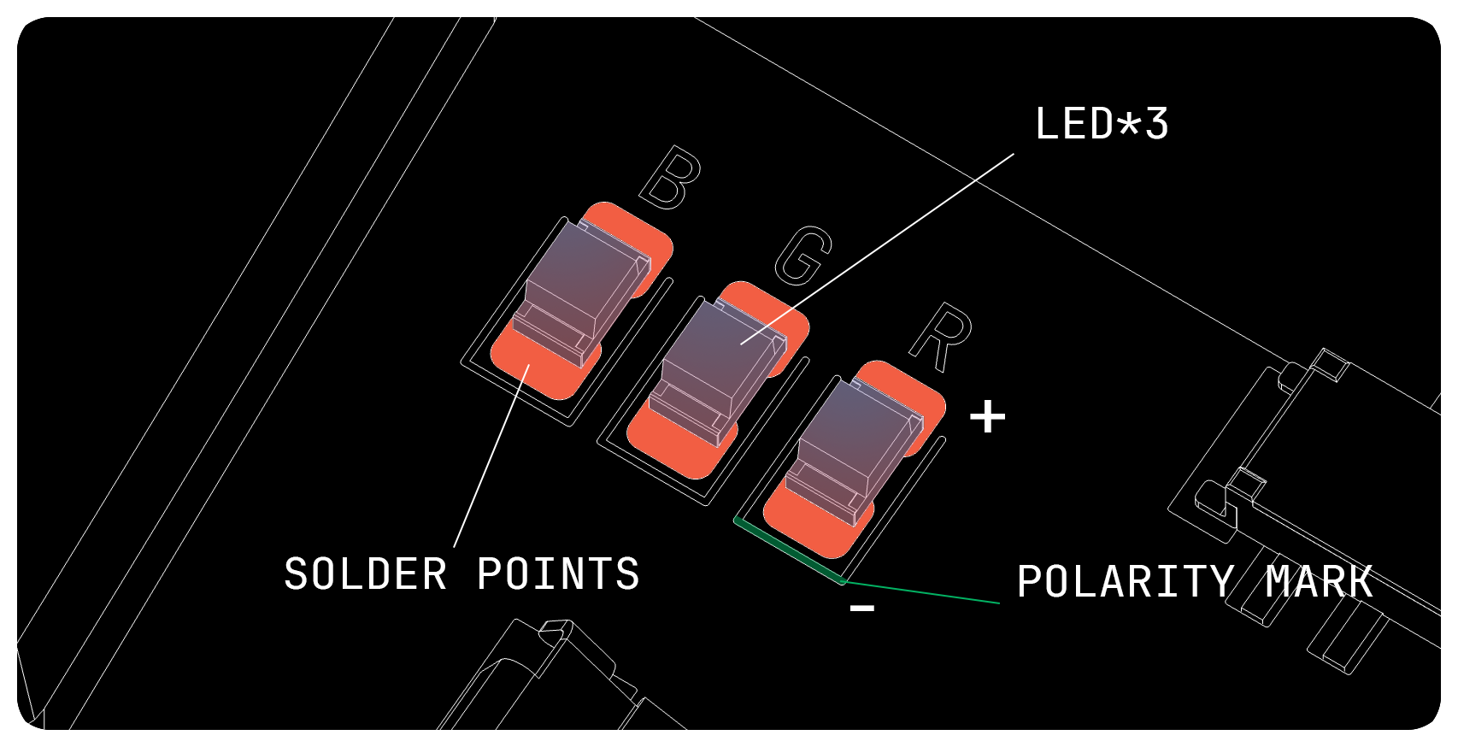
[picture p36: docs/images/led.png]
LED


1. LEDs are polarized components. Even if the LEDs are of the same size, different manufacturers may indicate polarity in different ways. Refer to the corresponding datasheet to confirm the correct polarity before soldering. Align the LED according to the silkscreen markings, where the closed side represents the negative (–) terminal and the open side represents the positive (+) terminal.
2. Apply solder to one pad, then reflow it while positioning the LED to secure it in place. After that, solder the opposite pad.
3. The color of the LED may be selected and installed according to user preference. For reference, the MCU pins corresponding to each silkscreen text (R, G, B) are connected identically on both the left and right sides.

> [!CAUTION]
> LEDs are highly sensitive to heat. Ensure that you verify the proper soldering temperature and limit the soldering duration to prevent damage.

### LED Resistors

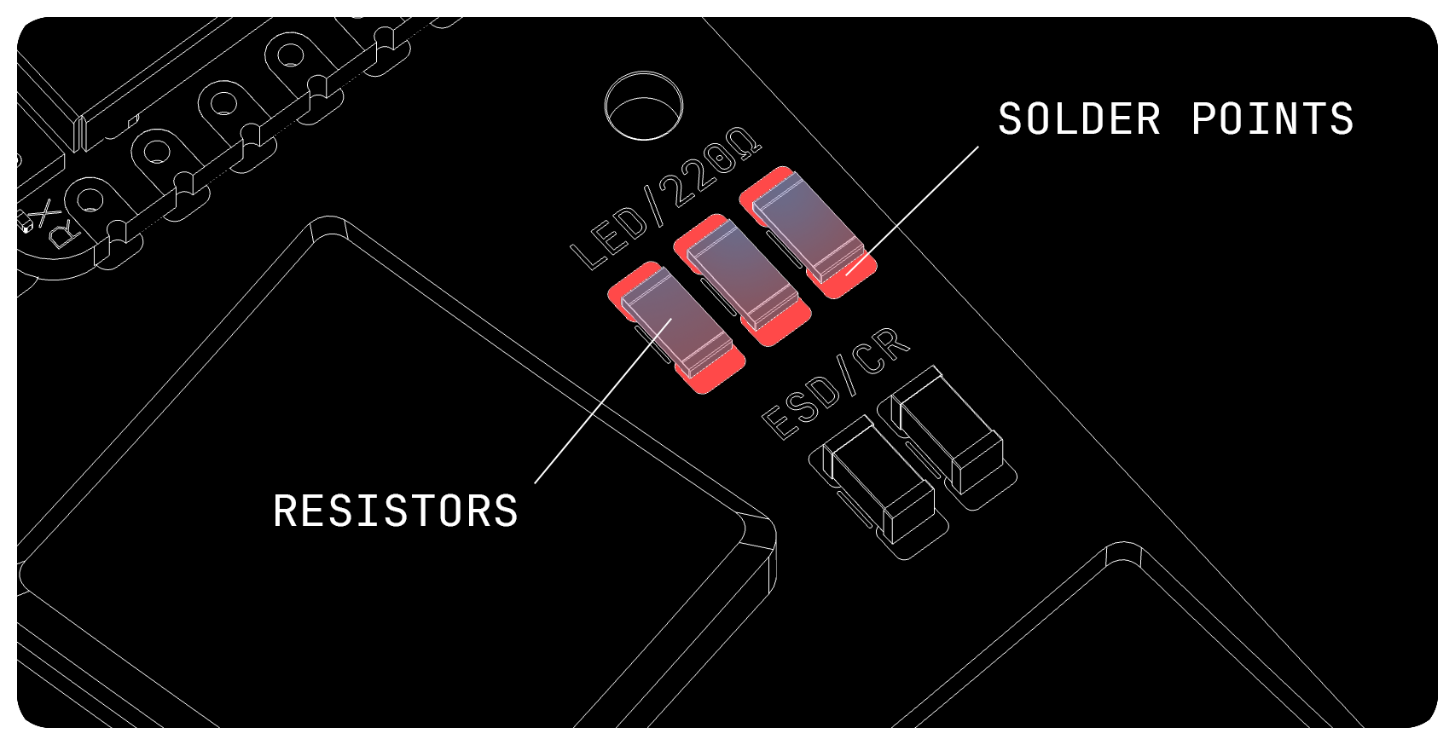
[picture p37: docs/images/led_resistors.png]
LED Resistors


1. Install three resistors for the LEDs. These components are non-polarized and therefore have no orientation requirements.
2. Apply solder to one pad, place the resistor in position, and reflow the solder to secure it. Then proceed to solder the remaining pad.

## (Optional) ESD Protection

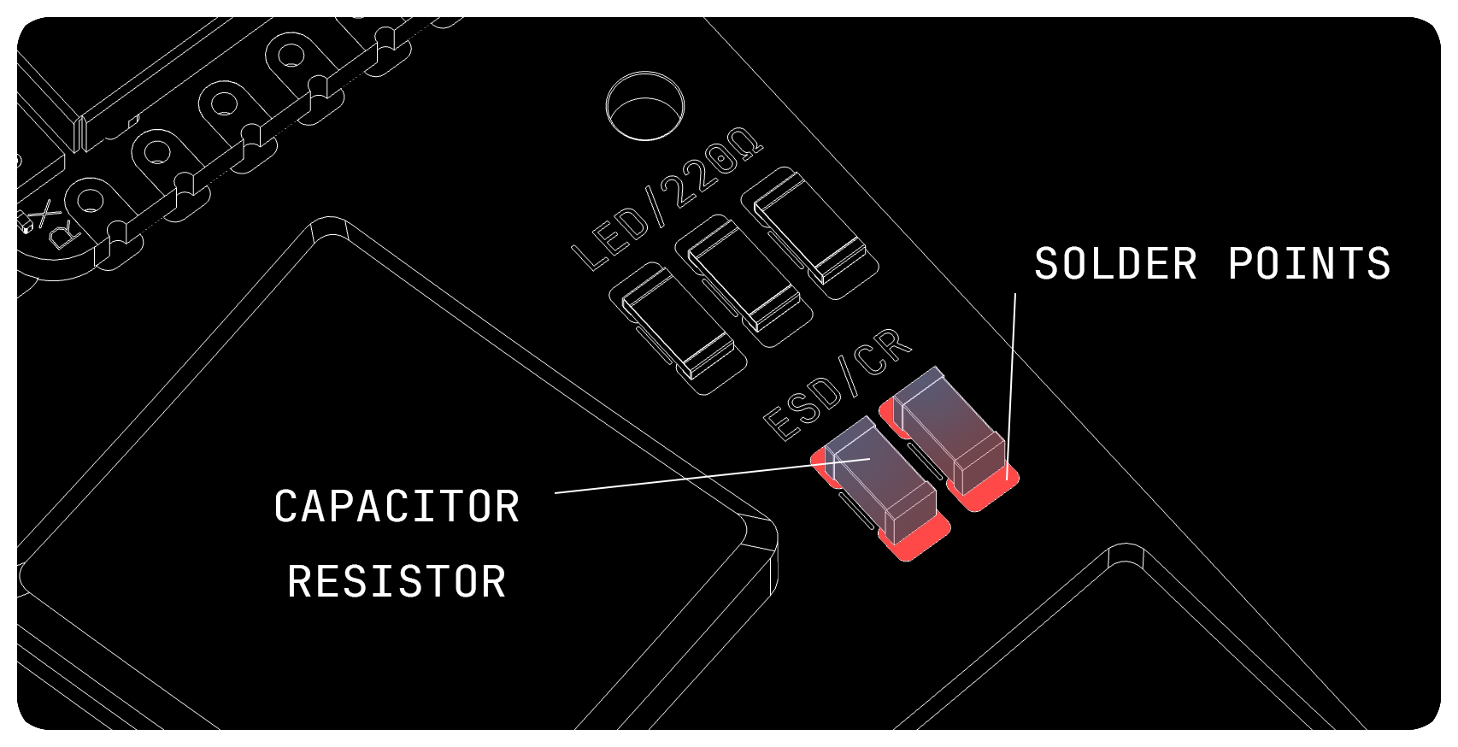
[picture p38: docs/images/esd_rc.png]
ESD Protection


1. Install the capacitor and resistor for ESD protection. There are two available mounting positions, and either component (capacitor or resistor) may be placed in either location. Both are non-polarized.

2. As with previous components, apply solder to one pad, position the part, and reflow the solder to secure it. Then proceed to solder the remaining pad.

## Diodes

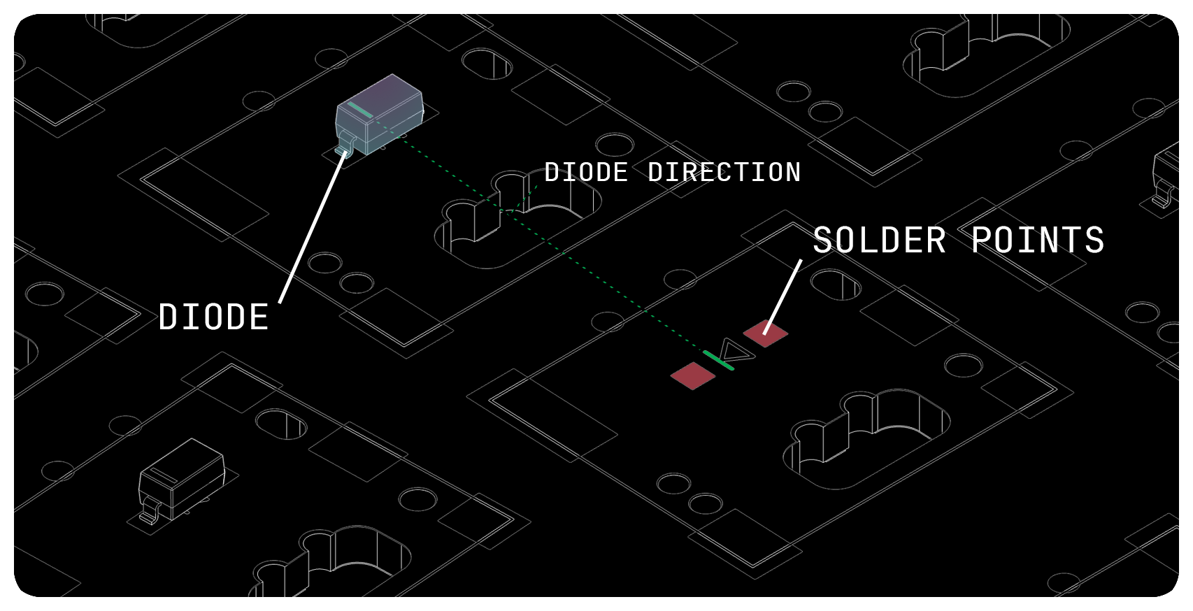
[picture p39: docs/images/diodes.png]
Diode


1. Orientation is critical: align the diode’s polarity marking with the silkscreen.
2. Due to limited space (ULP switches share space originally intended for LEDs), apply a **minimal solder amount**, centered between pads.

> [!TIP]
> After soldering, temporarily place the switch above the diode to confirm there is no interference. and testing!

## Switches

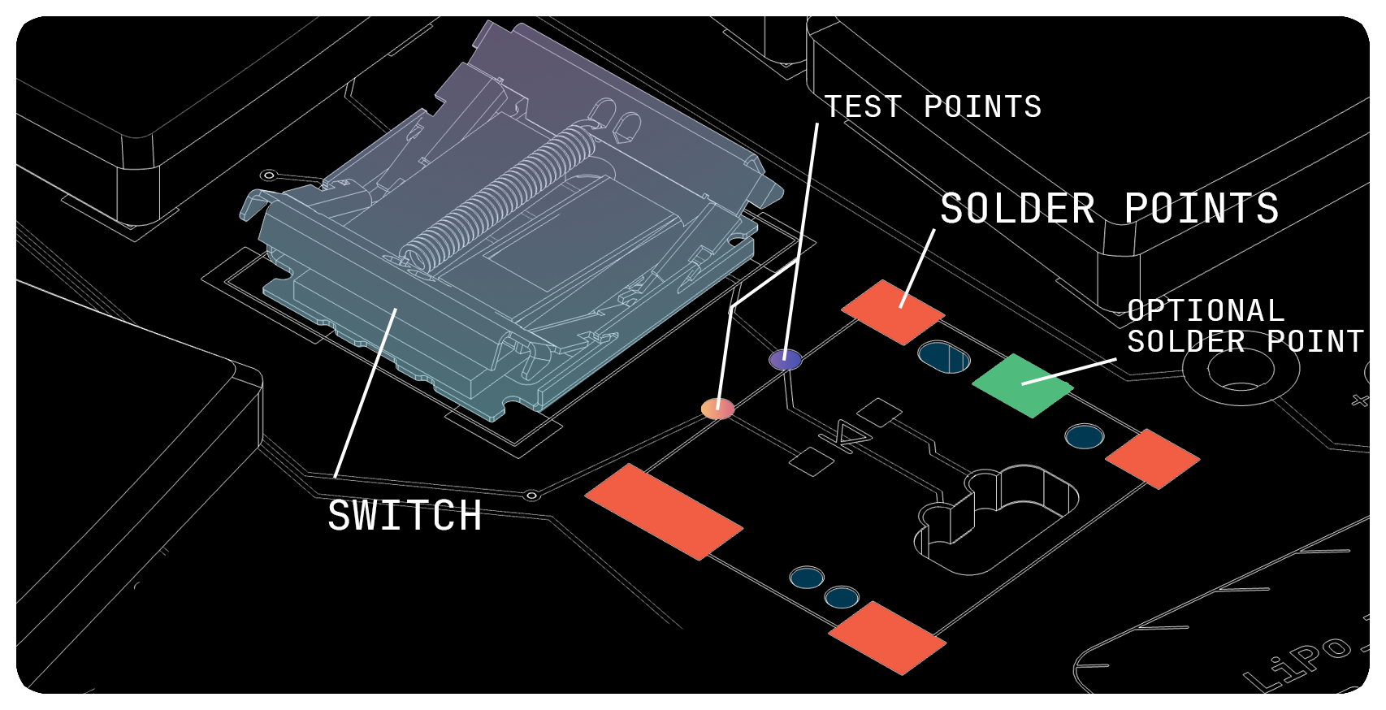
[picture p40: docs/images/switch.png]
Switch


This is often the most time-consuming step.

1. If castellated holes were not ordered, the through-holes may be damaged or deformed. Carefully trim protruding copper with a knife or nippers. Take care not to peel off the copper entirely.
2. Apply a small amount of solder to one pad.
3. Position the switch and reflow to tack it in place.
4. Solder the opposite pad, then the remaining corners (usually four points are sufficient).

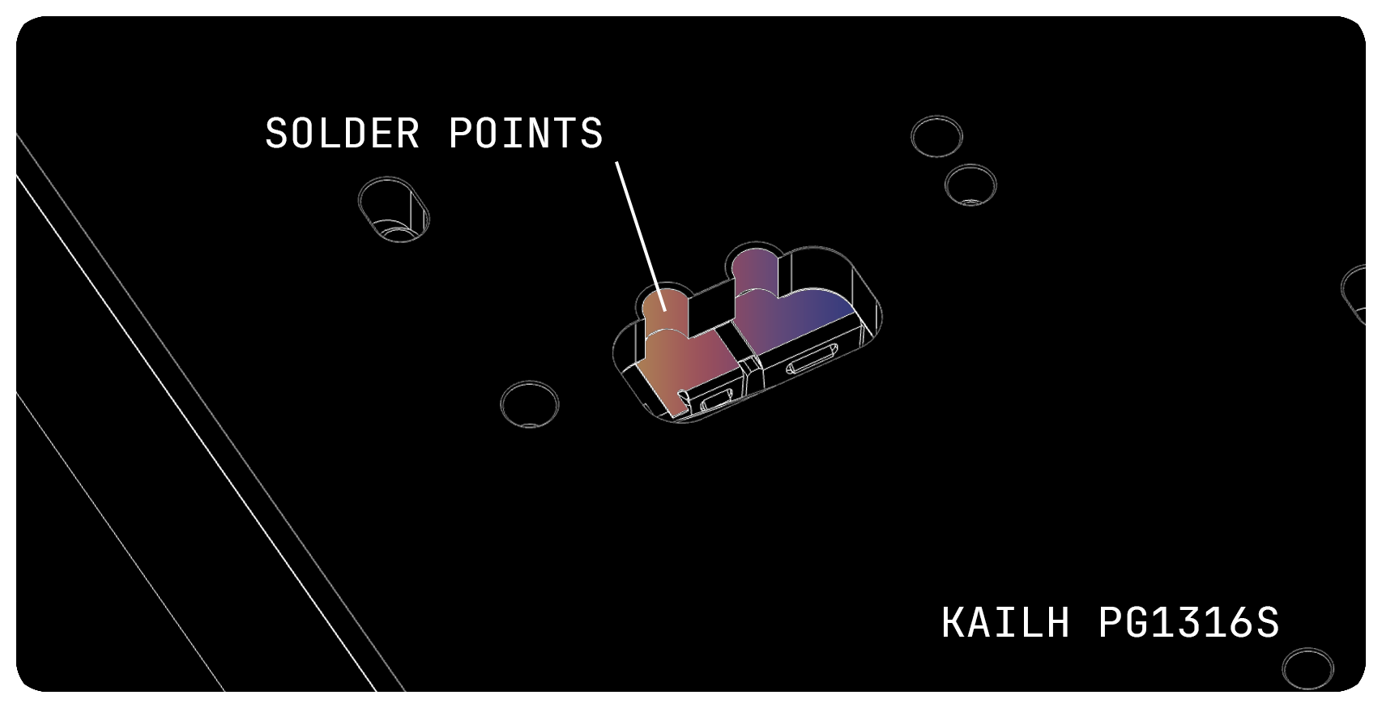
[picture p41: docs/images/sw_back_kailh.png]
Kailh

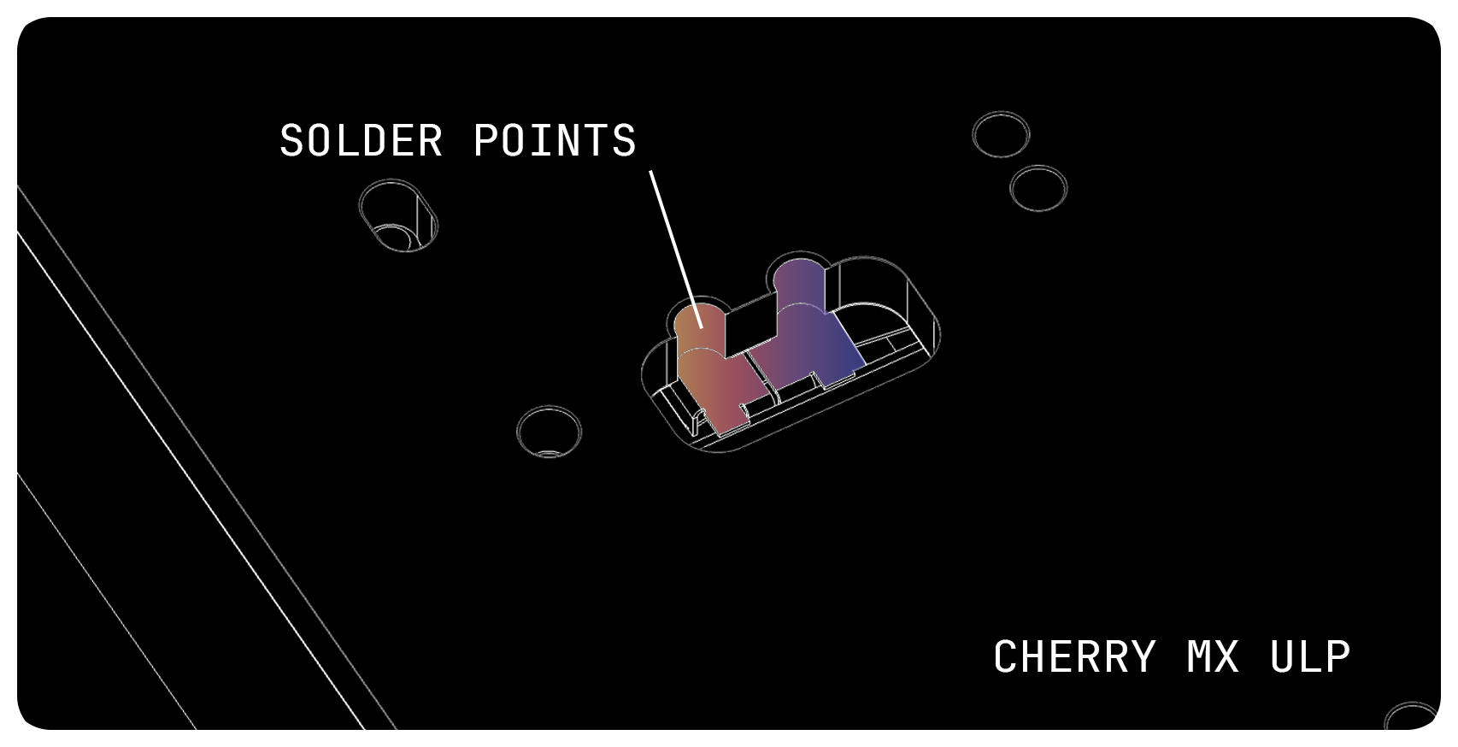
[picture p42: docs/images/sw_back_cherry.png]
Cherry


Flip the board to solder the switch contact points:

- Ensure good contact between the switch terminals and the through-hole walls.
- Use flux and controlled heat so solder bonds properly to both.

> [!TIP]
> Above each switch are two small test pads. Use a multimeter in diode mode to confirm continuity (flow direction: right → left).

## MCU Controller

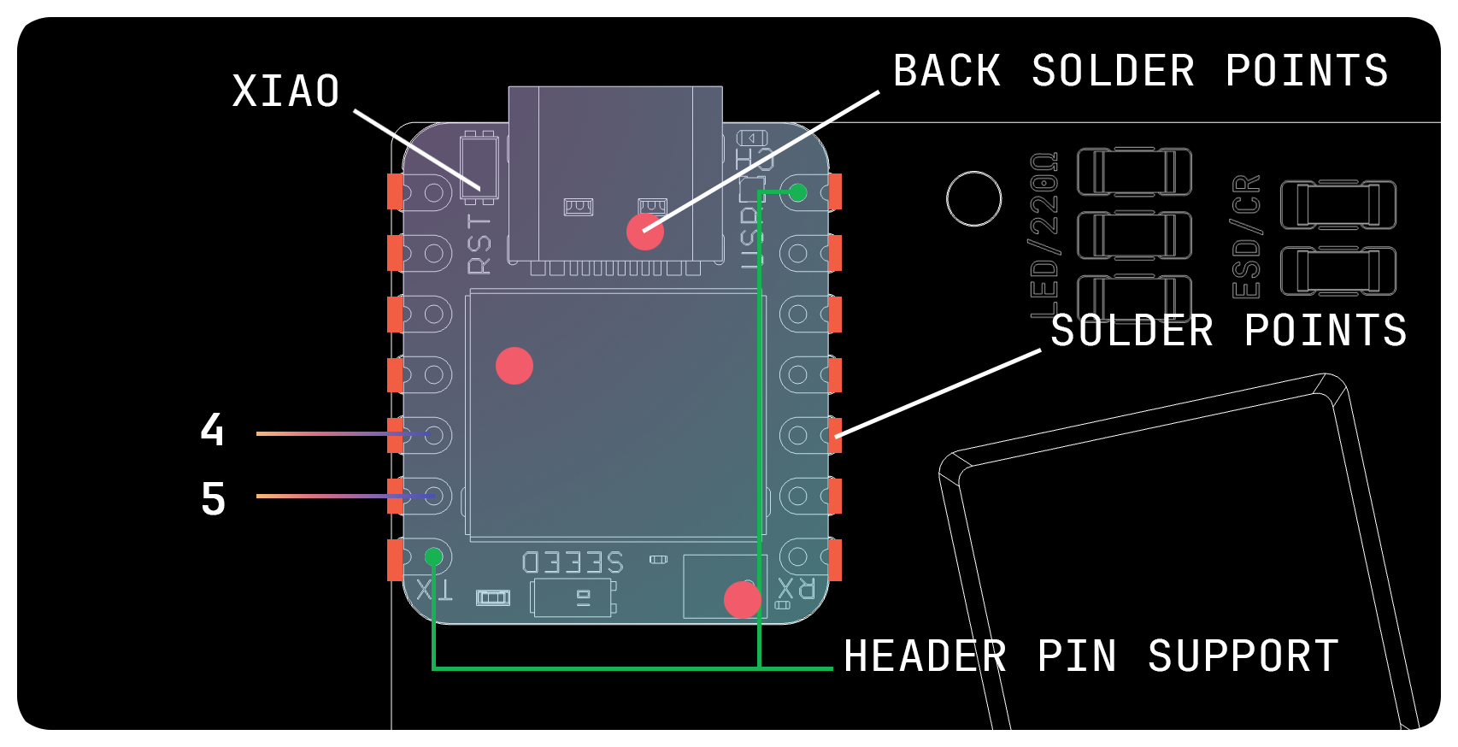
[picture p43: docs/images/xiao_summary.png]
Seeed XIAO nRF52840


1. **Flash firmware first** to verify the MCU is functional.

2. Position the MCU. If needed, insert header pins in the top-right and bottom-left corners for stability. (Remove after soldering)

3. Solder the castellated edges of the XIAO to the PCB pads.

⚠️ When soldering along the **outer edge (left side of the left PCB)**:
- Apply only minimal solder.
- Avoid bridges that may contact the aluminum case.

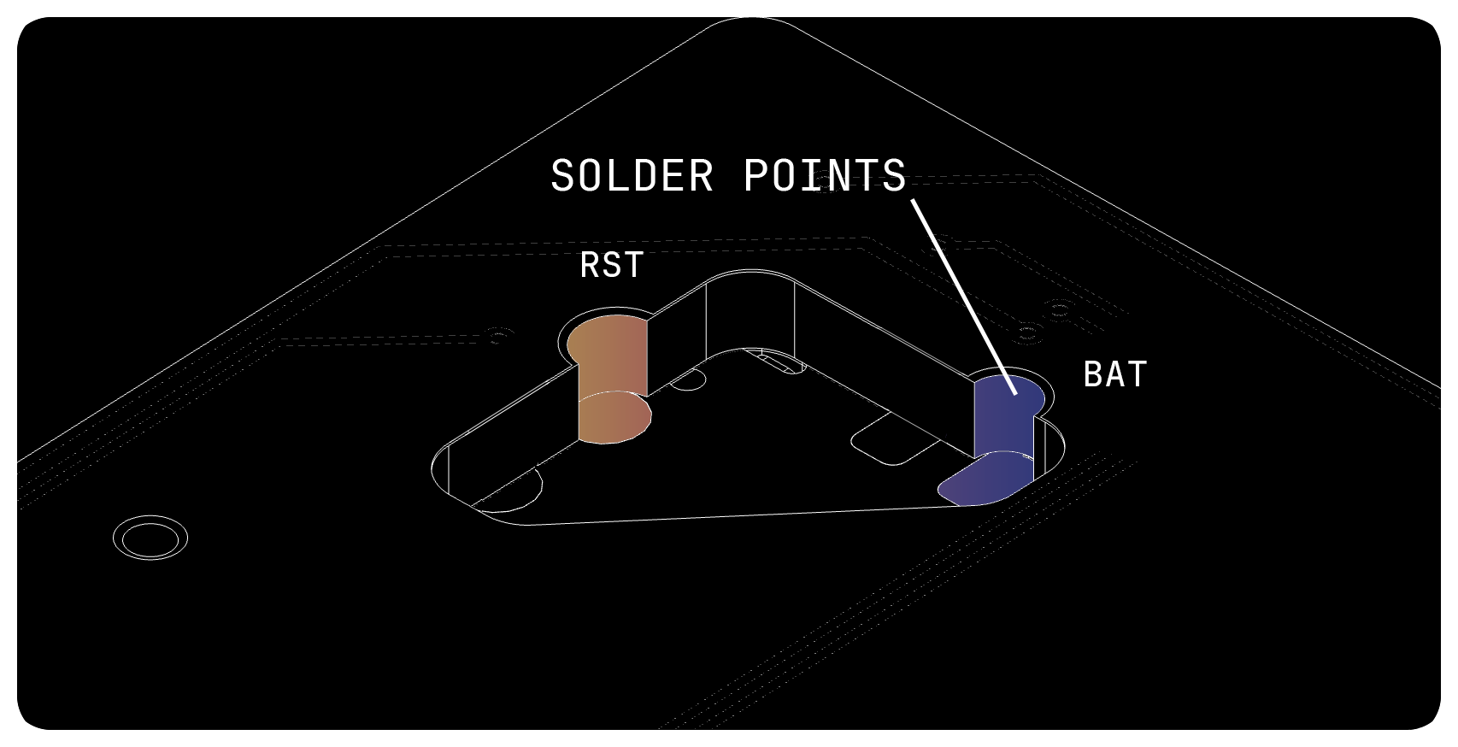
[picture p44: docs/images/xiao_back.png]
Back MCU


4. On the PCB backside, solder the 2 additional connection points. (Battery and Reset)
5. As with the switches, ensure solder bonds to both the XIAO and PCB.

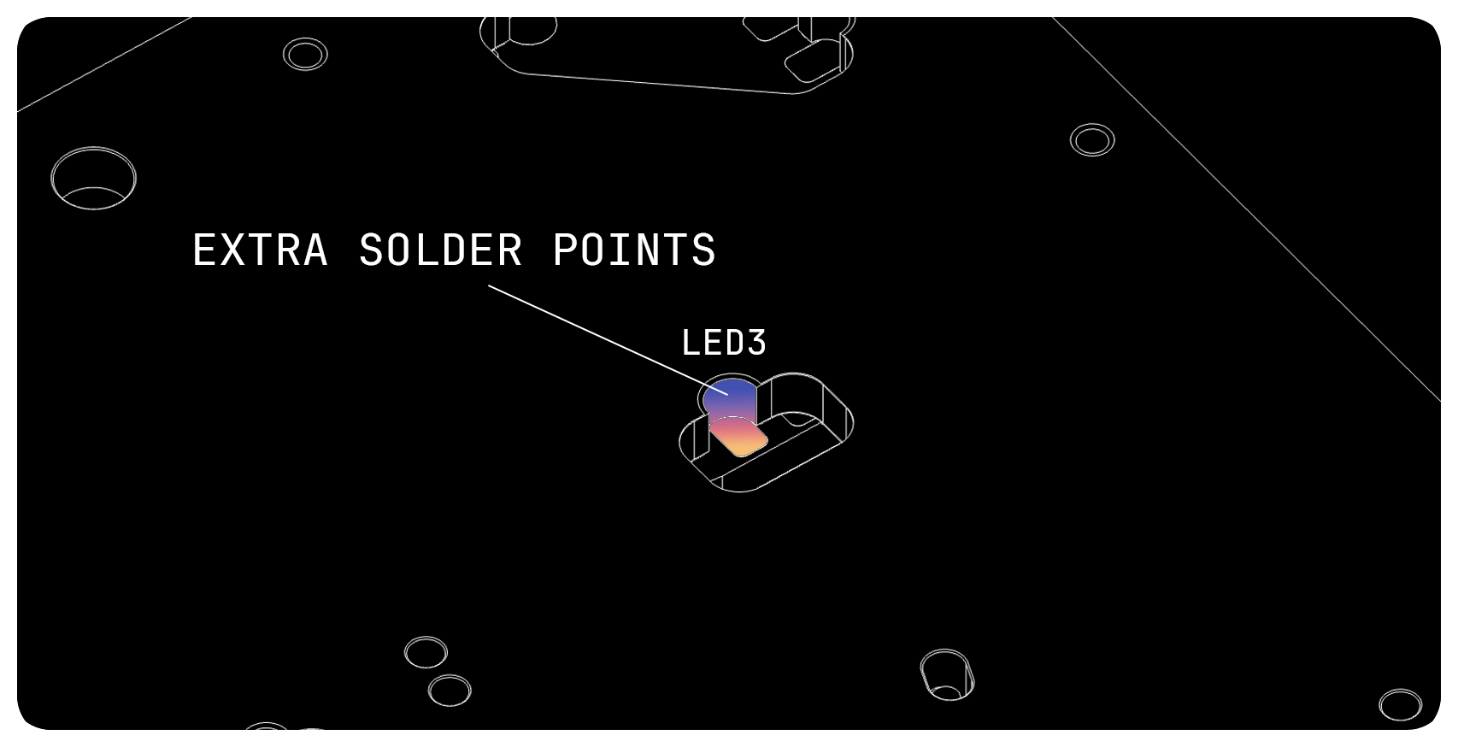
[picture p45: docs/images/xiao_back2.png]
Back MCU


6. (Optional) If you intend to use the LED, solder the additional pin located below.

## Battery

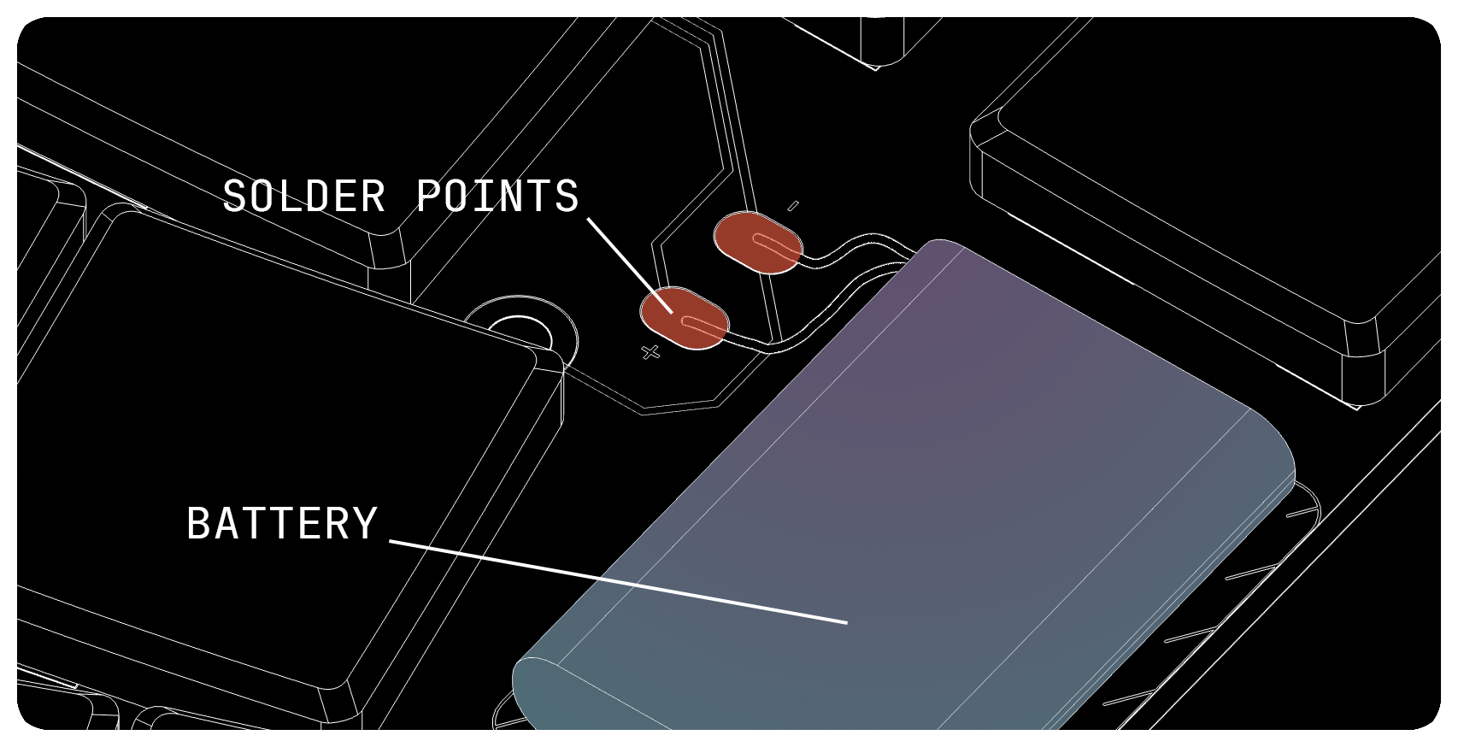
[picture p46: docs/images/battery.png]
Battery


> [!CAUTION]
> Confirm the power switch is **OFF** before beginning.

> [!WARNING]
> Lithium-polymer (LiPo) batteries are hazardous. Even minor damage can lead to thermal runaway. Prevent shorts, punctures, or impacts. Mishandling can cause severe injury or damage to components.

1. This design does not use JST or Molex connectors. Wires are soldered directly.
2. Trim wires to length. Strip 1–2 mm of insulation and tin the exposed ends.
3. Double-check polarity (red = positive, black = negative).
4. Insulate the positive terminal with RTV silicone, Kapton tape, or another reliable method.

## (Optional) Magnet

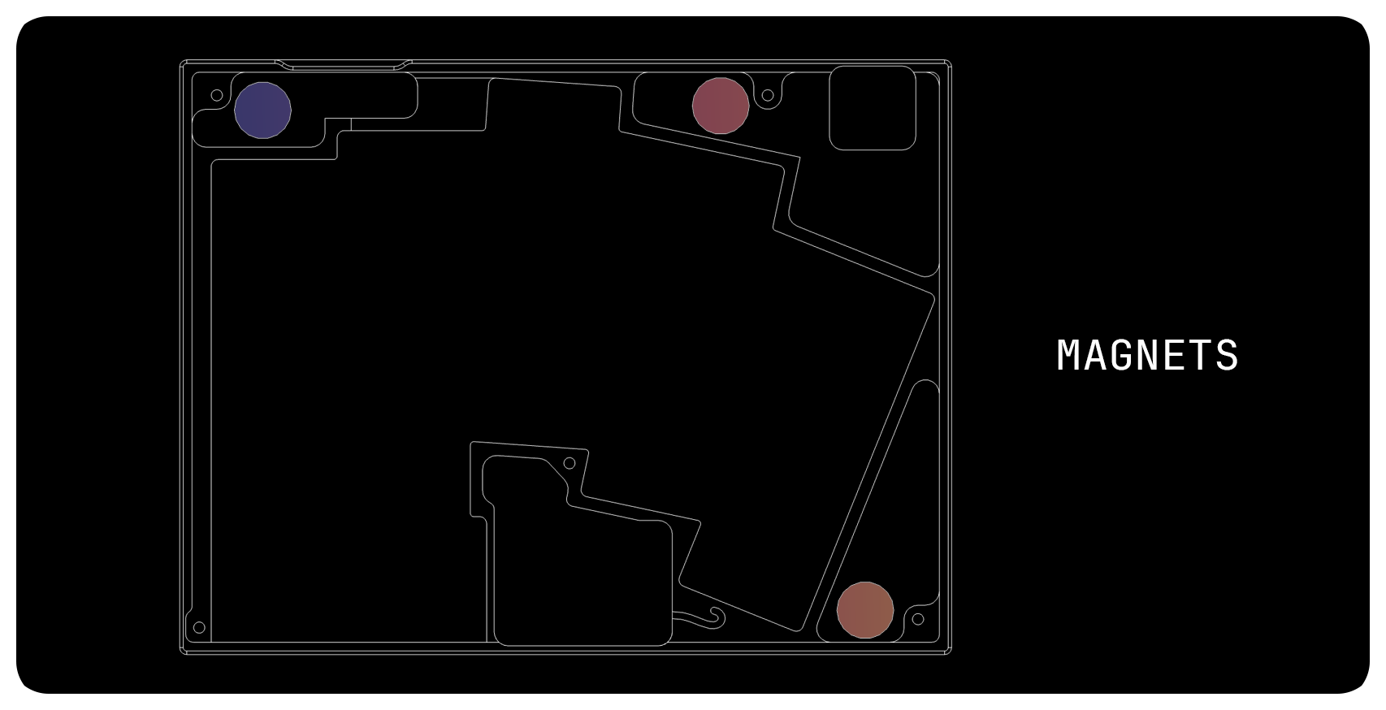
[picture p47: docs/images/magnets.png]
Magnets


Install magnets so that the polarity between the left and right cases is **aligned correctly**. ensuring they attract each other when closed.

Secure the magnets in place using **silicone adhesive** or **cyanoacrylate (instant glue)**.

## Case Assembly

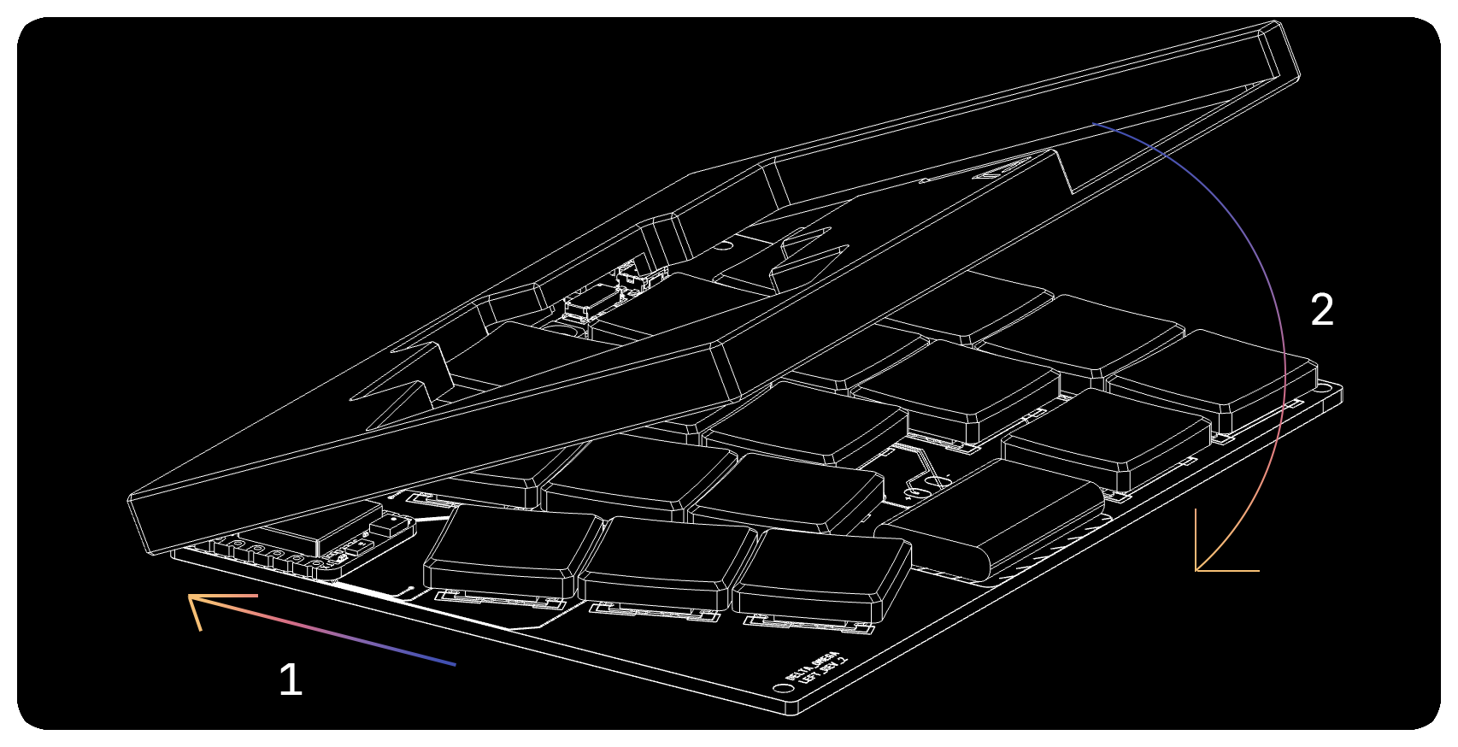
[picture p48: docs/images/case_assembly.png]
Assembly


1. Tilt the case slightly backward.
2. Align the rear ports first, then lower the front into place.

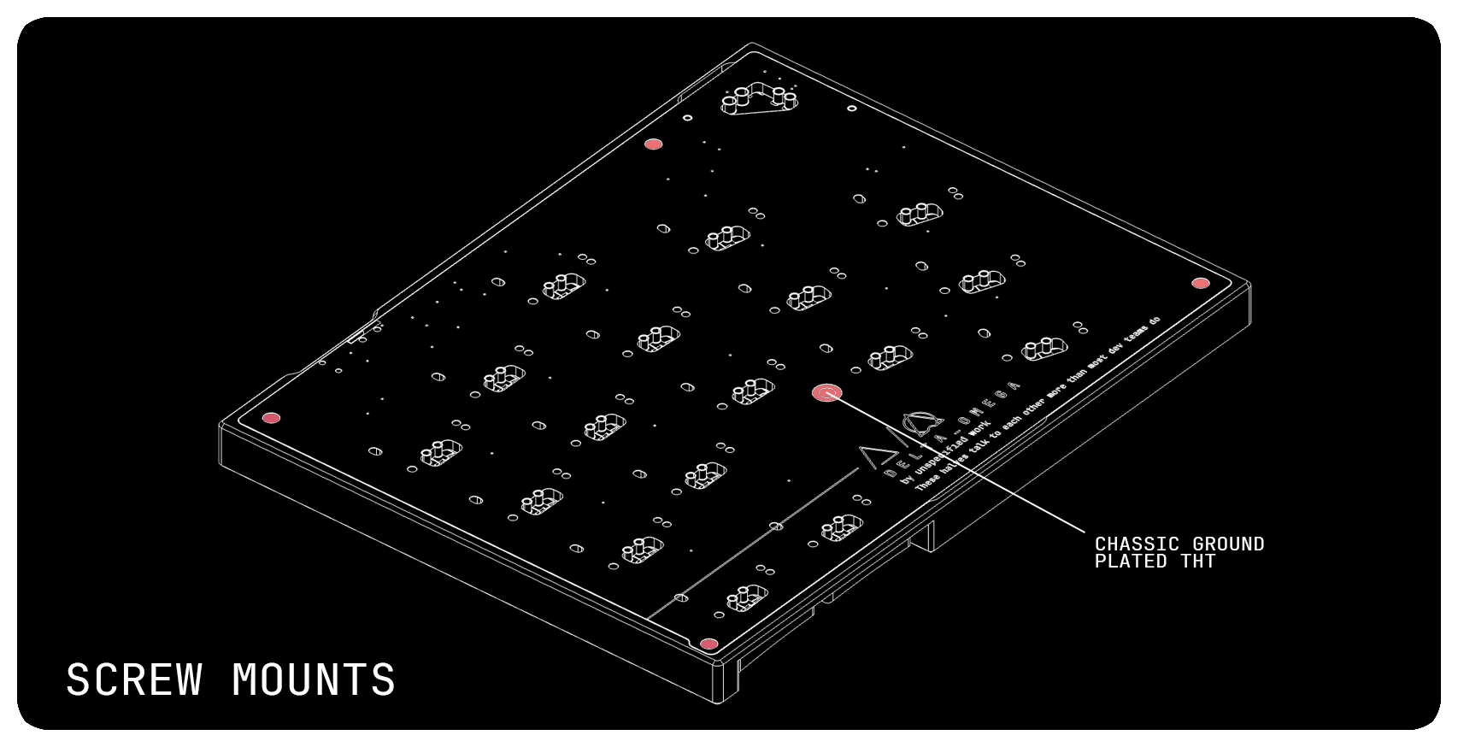
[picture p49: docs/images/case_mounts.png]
Case Mount


3. Fasten the PCB to the case using screws. Tightening should be firm but not excessive.
4. If using a cover plate, place it before fastening screws.

## Finish!

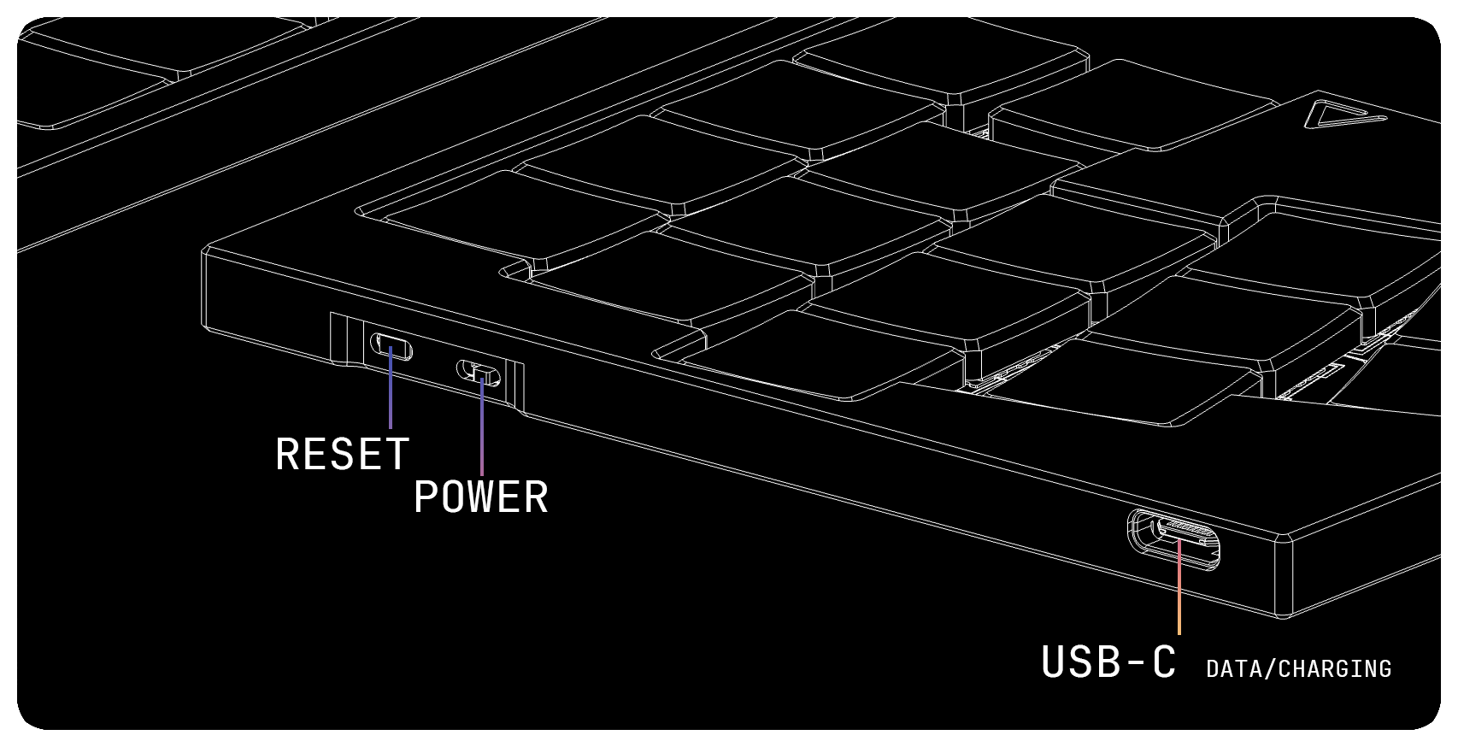
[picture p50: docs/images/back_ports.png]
Back side


Your build is now complete!

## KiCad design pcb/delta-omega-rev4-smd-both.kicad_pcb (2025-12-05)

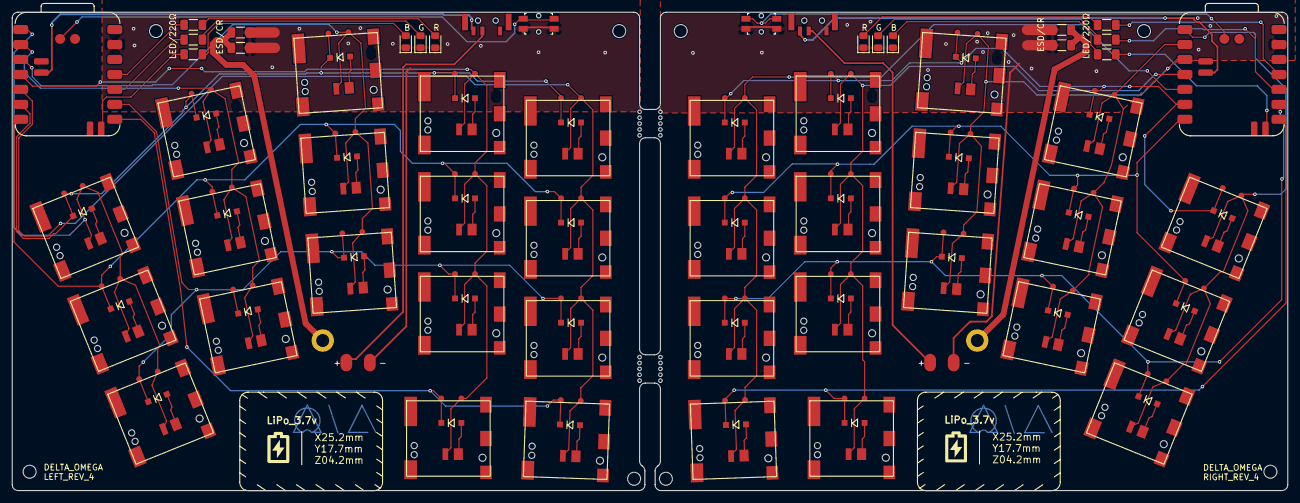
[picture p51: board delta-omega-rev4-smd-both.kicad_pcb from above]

Board: 2 copper layers, 216.5 x 81.2 mm, 102 parts (0 on the bottom side), 74 nets.

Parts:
C1, C2: C_1206_1NF; C_1206_3216Metric_Pad1.33x1.80mm_HandSolder
D1, D2, D3, D4, D5, D6, D7, D8, D9, D10, D11, D12, D13, D14, D15, D16, D17, D18, D19, D20, D21, D22, D23, D24, D25, D26, D27, D28, D29, D30, D31, D32, D33, D34: SOD123
H1, H2: mounting_hole_plated
L1, L4: LED_0805_R; LED_0805_2012Metric_Pad1.15x1.40mm_HandSolder
L2, L5: LED_0805_G; LED_0805_2012Metric_Pad1.15x1.40mm_HandSolder
L3, L6: LED_0805_B; LED_0805_2012Metric_Pad1.15x1.40mm_HandSolder
MCU1, MCU2: XIAO-nRF52840-SMD; smdXIAO-nRF52840
MH1, MH2, MH3, MH4, MH5, MH6, MH7, MH8: mounting_hole_npth
POWER1: PWR_SW; power_switch
PWR_SW: POWER1; power_switch
R1, R2, R3, R4, R5, R6: R_1206 _220R; R_1206_3216Metric_Pad1.30x1.75mm_HandSolder
R7, R8: R_1206_1MR; C_1206_3216Metric_Pad1.33x1.80mm_HandSolder
RST1, RST2: SW_RST; reset_switch_smd_side
SW1, SW2, SW3, SW4, SW5, SW6, SW7, SW8, SW9, SW10, SW11, SW12, SW13, SW14, SW15, SW16, SW17, SW18, SW19, SW20, SW21, SW22, SW23, SW24, SW25, SW26, SW27, SW28, SW29, SW30, SW31, SW32, SW33, SW34: ULP_SW; GENERIC_ULP_SMD
TH1, TH2: simple_tht_fp

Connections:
L_BATP: MCU2.15, POWER1.3
L_C1: MCU2.1, SW1.1, SW2.1, SW3.1
L_C2: MCU2.2, SW4.1, SW5.1, SW6.1
L_C3: MCU2.3, SW7.1, SW8.1, SW9.1
L_C4: MCU2.4, SW10.1, SW11.1, SW12.1, SW16.1
L_C5: MCU2.5, SW13.1, SW14.1, SW15.1, SW17.1
L_CGND: C2.1, R8.1
L_GND: C2.2, L4.1, L5.1, L6.1, MCU2.13, R8.2, RST1.2, RST1.4, TH1.1
L_LED1: L4.2, R1.2
L_LED2: L5.2, R2.2
L_LED3: L6.2, R3.2
L_LED_R1: MCU2.11, R1.1
L_LED_R2: MCU2.10, R2.1
L_LED_R3: MCU2.17, R3.1
L_R1: D3.4, D6.4, D9.4, D12.4, D15.4, MCU2.6, SW3.4, SW6.4, SW9.4, SW12.4, SW15.4
L_R2: D2.4, D5.4, D8.4, D11.4, D14.4, MCU2.7, SW2.4, SW5.4, SW8.4, SW11.4, SW14.4
L_R3: D1.4, D4.4, D7.4, D10.4, D13.4, MCU2.9, SW1.4, SW4.4, SW7.4, SW10.4, SW13.4
L_R4: D16.4, D17.4, MCU2.8, SW16.4, SW17.4
L_RAW: POWER1.2, TH1.2
L_RST: MCU2.21, RST1.1, RST1.3
R_BATP: MCU1.15, PWR_SW.3
R_C1: MCU1.1, SW18.1, SW19.1, SW20.1
R_C2: MCU1.2, SW21.1, SW22.1, SW23.1
R_C3: MCU1.3, SW24.1, SW25.1, SW26.1
R_C4: MCU1.4, SW27.1, SW28.1, SW29.1, SW33.1
R_C5: MCU1.5, SW30.1, SW31.1, SW32.1, SW34.1
R_CGND: C1.2, R7.2
R_GND: C1.1, L1.1, L2.1, L3.1, MCU1.13, R7.1, RST2.2, RST2.4, TH2.1
R_LED1: L1.2, R4.1
R_LED2: L2.2, R5.1
R_LED3: L3.2, R6.1
R_LED_R1: MCU1.11, R4.2
R_LED_R2: MCU1.10, R5.2
R_LED_R3: MCU1.17, R6.2
R_R1: D20.4, D23.4, D26.4, D29.4, D32.4, MCU1.6, SW20.4, SW23.4, SW26.4, SW29.4, SW32.4
R_R2: D19.4, D22.4, D25.4, D28.4, D31.4, MCU1.7, SW19.4, SW22.4, SW25.4, SW28.4, SW31.4
R_R3: D18.4, D21.4, D24.4, D27.4, D30.4, MCU1.9, SW18.4, SW21.4, SW24.4, SW27.4, SW30.4
R_R4: D33.4, D34.4, MCU1.8, SW33.4, SW34.4
R_RAW: PWR_SW.2, TH2.2
R_RST: MCU1.21, RST2.1, RST2.3
SW1_1: D1.5, SW1.2
SW2_1: D2.5, SW2.2
SW3_1: D3.5, SW3.2
SW4_1: D4.5, SW4.2
SW5_1: D5.5, SW5.2
SW6_1: D6.5, SW6.2
SW7_1: D7.5, SW7.2
SW8_1: D8.5, SW8.2
SW9_1: D9.5, SW9.2
SW10_1: D10.5, SW10.2
SW11_1: D11.5, SW11.2
SW12_1: D12.5, SW12.2
SW13_1: D13.5, SW13.2
SW14_1: D14.5, SW14.2
SW15_1: D15.5, SW15.2
SW16_1: D16.5, SW16.2
SW17_1: D17.5, SW17.2
SW18_1: D18.5, SW18.2
SW19_1: D19.5, SW19.2
SW20_1: D20.5, SW20.2
SW21_1: D21.5, SW21.2
SW22_1: D22.5, SW22.2
SW23_1: D23.5, SW23.2
SW24_1: D24.5, SW24.2
SW25_1: D25.5, SW25.2
SW26_1: D26.5, SW26.2
SW27_1: D27.5, SW27.2
SW28_1: D28.5, SW28.2
SW29_1: D29.5, SW29.2
SW30_1: D30.5, SW30.2
SW31_1: D31.5, SW31.2
SW32_1: D32.5, SW32.2
SW33_1: D33.5, SW33.2
SW34_1: D34.5, SW34.2

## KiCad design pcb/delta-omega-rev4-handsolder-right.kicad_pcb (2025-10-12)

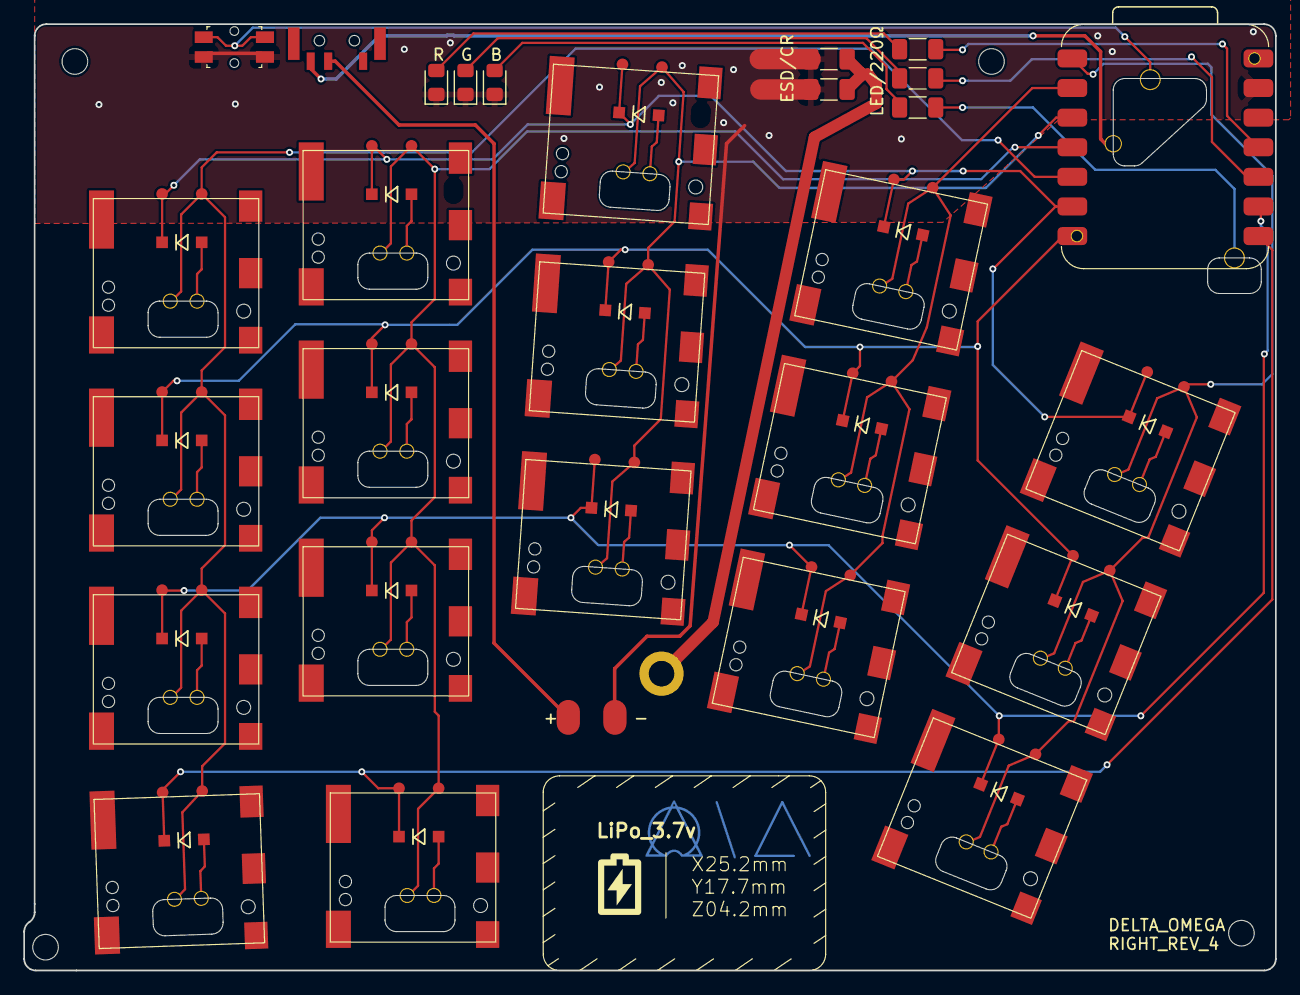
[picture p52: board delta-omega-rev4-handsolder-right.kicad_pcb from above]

Board: 2 copper layers, 107.4 x 81.2 mm, 33 parts (0 on the bottom side), 35 nets.

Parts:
C1: C_1206_3216Metric_Pad1.33x1.80mm_HandSolder
H2: mounting_hole_plated
L1, L2, L3: LED_0805_2012Metric_Pad1.15x1.40mm_HandSolder
MCU1: XIAO-nRF52840-SMD; XIAO-nRF52840
MH2, MH4, MH6, MH8: mounting_hole_npth
R1, R2, R3: R_1206_3216Metric_Pad1.30x1.75mm_HandSolder
R1#2: C_1206_3216Metric_Pad1.33x1.80mm_HandSolder
RST2: reset_switch_smd_side
SW18, SW19, SW20, SW21, SW22, SW23, SW24, SW25, SW26, SW27, SW28, SW29, SW30, SW31, SW32, SW33, SW34: ULP_SW; GENERIC_ULP_HANDSOLDER
TH2: simple_tht_fp

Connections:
R_C1: MCU1.1, SW18.1, SW19.1, SW20.1
R_C2: MCU1.2, SW21.1, SW22.1, SW23.1
R_C3: MCU1.3, SW24.1, SW25.1, SW26.1
R_C4: MCU1.4, SW27.1, SW28.1, SW29.1, SW33.1
R_C5: MCU1.5, SW30.1, SW31.1, SW32.1, SW34.1
R_CGND: C1.2, R1#2.2
R_GND: C1.1, L1.1, L2.1, L3.1, MCU1.13, R1#2.1, RST2.2, RST2.4, TH2.1
R_LED1: L1.2, R1.1
R_LED2: L2.2, R2.1
R_LED3: L3.2, R3.1
R_LED_R1: MCU1.11, R1.2
R_LED_R2: MCU1.10, R2.2
R_LED_R3: MCU1.17, R3.2
R_R1: MCU1.6, SW20.4, SW23.4, SW26.4, SW29.4, SW32.4
R_R2: MCU1.7, SW19.4, SW22.4, SW25.4, SW28.4, SW31.4
R_R3: MCU1.9, SW18.4, SW21.4, SW24.4, SW27.4, SW30.4
R_R4: MCU1.8, SW33.4, SW34.4
R_RST: MCU1.21, RST2.1, RST2.3
SW18_1: SW18.2, SW18.5
SW19_1: SW19.2, SW19.5
SW20_1: SW20.2, SW20.5
SW21_1: SW21.2, SW21.5
SW22_1: SW22.2, SW22.5
SW23_1: SW23.2, SW23.5
SW24_1: SW24.2, SW24.5
SW25_1: SW25.2, SW25.5
SW26_1: SW26.2, SW26.5
SW27_1: SW27.2, SW27.5
SW28_1: SW28.2, SW28.5
SW29_1: SW29.2, SW29.5
SW30_1: SW30.2, SW30.5
SW31_1: SW31.2, SW31.5
SW32_1: SW32.2, SW32.5
SW33_1: SW33.2, SW33.5
SW34_1: SW34.2, SW34.5

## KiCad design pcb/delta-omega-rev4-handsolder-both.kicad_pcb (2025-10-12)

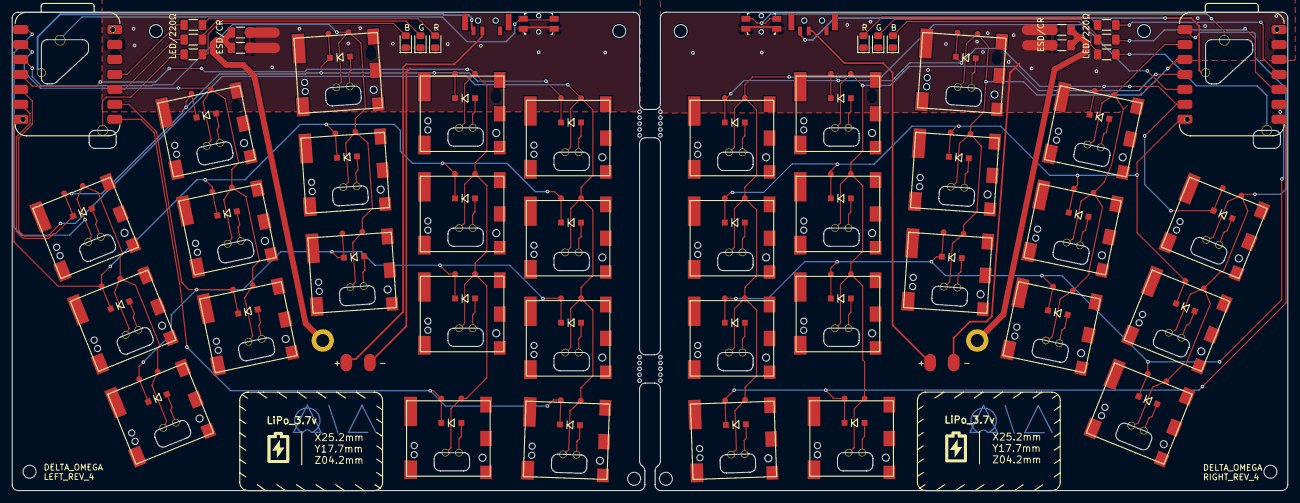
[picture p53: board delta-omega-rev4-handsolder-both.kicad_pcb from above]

Board: 2 copper layers, 216.5 x 81.2 mm, 66 parts (0 on the bottom side), 70 nets.

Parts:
C1, C1#2: C_1206_3216Metric_Pad1.33x1.80mm_HandSolder
H1, H2: mounting_hole_plated
L1, L1#2, L2, L2#2, L3, L3#2: LED_0805_2012Metric_Pad1.15x1.40mm_HandSolder
MCU1, MCU2: XIAO-nRF52840-SMD; XIAO-nRF52840
MH1, MH2, MH3, MH4, MH5, MH6, MH7, MH8: mounting_hole_npth
R1, R1#3, R2, R2#2, R3, R3#2: R_1206_3216Metric_Pad1.30x1.75mm_HandSolder
R1#2, R1#4: C_1206_3216Metric_Pad1.33x1.80mm_HandSolder
RST1, RST2: reset_switch_smd_side
SW1, SW2, SW3, SW4, SW5, SW6, SW7, SW8, SW9, SW10, SW11, SW12, SW13, SW14, SW15, SW16, SW17, SW18, SW19, SW20, SW21, SW22, SW23, SW24, SW25, SW26, SW27, SW28, SW29, SW30, SW31, SW32, SW33, SW34: ULP_SW; GENERIC_ULP_HANDSOLDER
TH1, TH2: simple_tht_fp

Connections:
L_C1: MCU2.1, SW1.1, SW2.1, SW3.1
L_C2: MCU2.2, SW4.1, SW5.1, SW6.1
L_C3: MCU2.3, SW7.1, SW8.1, SW9.1
L_C4: MCU2.4, SW10.1, SW11.1, SW12.1, SW16.1
L_C5: MCU2.5, SW13.1, SW14.1, SW15.1, SW17.1
L_CGND: C1#2.1, R1#2.1
L_GND: C1#2.2, L1.1, L2#2.1, L3#2.1, MCU2.13, R1#2.2, RST1.2, RST1.4, TH1.1
L_LED1: L1.2, R1#3.2
L_LED2: L2#2.2, R2#2.2
L_LED3: L3#2.2, R3#2.2
L_LED_R1: MCU2.11, R1#3.1
L_LED_R2: MCU2.10, R2#2.1
L_LED_R3: MCU2.17, R3#2.1
L_R1: MCU2.6, SW3.4, SW6.4, SW9.4, SW12.4, SW15.4
L_R2: MCU2.7, SW2.4, SW5.4, SW8.4, SW11.4, SW14.4
L_R3: MCU2.9, SW1.4, SW4.4, SW7.4, SW10.4, SW13.4
L_R4: MCU2.8, SW16.4, SW17.4
L_RST: MCU2.21, RST1.1, RST1.3
R_C1: MCU1.1, SW18.1, SW19.1, SW20.1
R_C2: MCU1.2, SW21.1, SW22.1, SW23.1
R_C3: MCU1.3, SW24.1, SW25.1, SW26.1
R_C4: MCU1.4, SW27.1, SW28.1, SW29.1, SW33.1
R_C5: MCU1.5, SW30.1, SW31.1, SW32.1, SW34.1
R_CGND: C1.2, R1#4.2
R_GND: C1.1, L1#2.1, L2.1, L3.1, MCU1.13, R1#4.1, RST2.2, RST2.4, TH2.1
R_LED1: L1#2.2, R1.1
R_LED2: L2.2, R2.1
R_LED3: L3.2, R3.1
R_LED_R1: MCU1.11, R1.2
R_LED_R2: MCU1.10, R2.2
R_LED_R3: MCU1.17, R3.2
R_R1: MCU1.6, SW20.4, SW23.4, SW26.4, SW29.4, SW32.4
R_R2: MCU1.7, SW19.4, SW22.4, SW25.4, SW28.4, SW31.4
R_R3: MCU1.9, SW18.4, SW21.4, SW24.4, SW27.4, SW30.4
R_R4: MCU1.8, SW33.4, SW34.4
R_RST: MCU1.21, RST2.1, RST2.3
SW1_1: SW1.2, SW1.5
SW2_1: SW2.2, SW2.5
SW3_1: SW3.2, SW3.5
SW4_1: SW4.2, SW4.5
SW5_1: SW5.2, SW5.5
SW6_1: SW6.2, SW6.5
SW7_1: SW7.2, SW7.5
SW8_1: SW8.2, SW8.5
SW9_1: SW9.2, SW9.5
SW10_1: SW10.2, SW10.5
SW11_1: SW11.2, SW11.5
SW12_1: SW12.2, SW12.5
SW13_1: SW13.2, SW13.5
SW14_1: SW14.2, SW14.5
SW15_1: SW15.2, SW15.5
SW16_1: SW16.2, SW16.5
SW17_1: SW17.2, SW17.5
SW18_1: SW18.2, SW18.5
SW19_1: SW19.2, SW19.5
SW20_1: SW20.2, SW20.5
SW21_1: SW21.2, SW21.5
SW22_1: SW22.2, SW22.5
SW23_1: SW23.2, SW23.5
SW24_1: SW24.2, SW24.5
SW25_1: SW25.2, SW25.5
SW26_1: SW26.2, SW26.5
SW27_1: SW27.2, SW27.5
SW28_1: SW28.2, SW28.5
SW29_1: SW29.2, SW29.5
SW30_1: SW30.2, SW30.5
SW31_1: SW31.2, SW31.5
SW32_1: SW32.2, SW32.5
SW33_1: SW33.2, SW33.5
SW34_1: SW34.2, SW34.5

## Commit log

2025-08-15 prototype v1 done.
2025-08-15 Add more todos
    many good ppl ask or criticism for this. really appreciated. i love this powerful community.
2025-08-17 Add some improvements for prototype
2025-09-08 Added firmware link Added Led indicator issue Added Some quick links
2025-09-13 Removed LED Indicator. and clean up docs.
    - NeoPixel still drains so much power. and not a handy feature.
2025-10-12 Release ready
    [delta-omega-rev4-handsolder-both.kicad_pcb, delta-omega-rev4-handsolder-left.kicad_pcb, delta-omega-rev4-handsolder-right.kicad_pcb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]
2025-10-12 Add prototype gallery
2025-10-28 Fix PCB file name in pcb/README.md
2025-12-05 pcb: add smd pcb and gerbers
    [bom.csv, delta-omega-rev4-smd-both.kicad_pcb, positions.csv]
